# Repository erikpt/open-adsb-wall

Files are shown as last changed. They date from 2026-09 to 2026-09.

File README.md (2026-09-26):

# TailWatch S3 (starter)

MatrixPortal S3 + 128x64 HUB75 panel.

## On the CIRCUITPY drive

- `firmware/boot.py`
- `firmware/code.py`
- `prefs.json` (copy from `firmware/prefs.example.json`)
- `settings.toml` (Wi-Fi only -- copy from `firmware/settings.toml.example`; do **not** set `CIRCUITPY_WEB_API_PASSWORD`)
- `firmware/www/index.html`
- `firmware/lib/prefs.py`, `firmware/lib/sun.py`, `firmware/lib/schedule.py`, `firmware/lib/bbox.py`, `firmware/lib/urldecode.py`, `firmware/lib/tz.py`, `firmware/lib/dim.py`, `firmware/lib/hero.py`
- `firmware/lib/enrich.py`, `firmware/lib/filters.py` (on-device airline lookup + heli/mil/GA filters, issue #2: no cloud)
- `firmware/lib/logos/` (50 generated badge BMPs, ~17.7 KB total -- see `tools/gen_badges.py`)
- `firmware/lib/wifisettings.py` (settings.toml Wi-Fi writer, AP-mode provisioning, issue #11)
- `firmware/lib/setupscreen.py` (panel setup-AP credentials screen, issue #11)
- `firmware/lib/linkwatch.py` (station Wi-Fi drop detection + bounded reconnect watchdog)
- `firmware/lib/httpclient.py` (shared, always-closing adafruit_requests client pattern for the future `firmware/lib/net.py`)

Libraries from the CircuitPython bundle:

- `adafruit_httpserver`
- `adafruit_ntp`
- `adafruit_imageload` (decodes `firmware/lib/logos/*.bmp` badges)
- `adafruit_display_text` (setup-AP credentials screen, `firmware/lib/setupscreen.py`)
- `adafruit_requests`, `adafruit_connection_manager` (needed once `firmware/lib/net.py` starts making HTTPS requests via `firmware/lib/httpclient.py`)

`tests/` (host-side checks, e.g. `tests/test_hero.py`) is plain Python for a
computer's `python3` and is **not** copied to the CIRCUITPY drive.

## Updating files (read-only USB drive)

`firmware/boot.py` remounts CIRCUITPY writable for the firmware so the web UI
can save `/prefs.json` (and `/prefs.bak`). Side effect: in normal operation the
USB drive is **read-only** to your computer.

To update `firmware/code.py`, `firmware/lib/`, or `firmware/www/`:

1. Plug into USB, **hold the UP button**, tap RESET (or power-cycle), and keep
   holding UP about 2 s until the drive mounts.
2. The drive is now writable over USB; copy files. (Web UI prefs saves return
   503 in this mode.)
3. Tap RESET without holding anything to return to normal mode.

Do **not** hold BOOT for this: BOOT at power-up enters the ESP32-S3 ROM
bootloader, not CircuitPython.

Fallbacks: enter safe mode (press RESET, then press RESET again during the ~1 s
yellow status-LED blink); safe mode skips `firmware/boot.py` and leaves the drive
USB-writable. Or from the serial REPL: `import os; os.rename("/boot.py", "/boot.off")`
then hard reset.

`firmware/boot.py` only runs on hard reset/power-up; a soft reload (Ctrl-D,
file save) does not re-run it.

## Behavior

- If an existing board's `settings.toml` has `CIRCUITPY_WEB_API_PASSWORD`, delete
  that line and hard reset. Otherwise Web Workflow holds port 80, the TailWatch
  UI prints "http start failed", and the filesystem is exposed on the LAN.
- Local UI: `http://<s3-ip>/` after it joins Wi-Fi
- Prefs saved on device (`/prefs.json`)
- Sleep blanks the panel (`brightness = 0`)
- Night mode: off / fixed hours / after local sunset
- Day / night / max brightness sliders
- Filters stored: `hide_heli`, `hide_ga`, `hide_mil`
- 10 miles each way → OpenSky bbox (printed to serial until `firmware/lib/net.py` is wired)
- No cloud API -- OpenSky is called directly from the device; hero selection, filters, and airline badges all run on-device (`firmware/lib/hero.py`, `firmware/lib/filters.py`, `firmware/lib/enrich.py`, `firmware/lib/logos/`)
- If Wi-Fi drops, TailWatch retries the join for ~4 min (serial shows `wifi:` lines), moves the web UI to the new IP, and otherwise reboots into the setup AP.

## First-time / new Wi-Fi setup

If `CIRCUITPY_WIFI_SSID` is empty, or the device can't join it, TailWatch
starts its own setup access point:

1. The panel shows four lines: `WIFI SETUP`, the AP name `TailWatch-XXXX`,
   the AP password (`pw xxxxxxxx`), and `192.168.4.1`. The same line is
   printed to serial.
2. On your phone or laptop, join `TailWatch-XXXX` with that password.
3. Open `http://192.168.4.1/`. The Wi-Fi form is shown above the regular
   prefs form, with a note that setup mode is active.
4. Enter your home network's SSID and password (or tick "Open network") and
   tap **Save Wi-Fi & restart**. TailWatch writes `/settings.toml` and hard
   resets to join it.
5. Reconnect your phone to your normal Wi-Fi; find the device's new address
   on serial or in your router's device list.

If the saved credentials are wrong, or that network isn't reachable, the
device comes back up as the `TailWatch-XXXX` setup AP, so there's always an
in-field way to recover. With no SSID configured at all, it stays in setup
mode indefinitely; with an SSID configured but unreachable, it retries the
join automatically after about 10 minutes of no setup-page activity.

Wi-Fi saves need a normal boot (not booted with UP held) since that mode
leaves the filesystem read-only to `firmware/code.py`; a save attempted then
returns 503 and the device does not reboot.

## Next

1. `firmware/lib/net.py`: implement `poll_card()` as an HTTPS GET to OpenSky's `/api/states/all` (bbox + `extended=1`)
2. Draw the returned card with `displayio` / `terminalio` (`firmware/lib/card.py`)
3. Wire `firmware/code.py`'s poll loop: `net.poll_card()` → `filters.apply()` → `hero.select()` → `card.draw()`
4. ~~AP-mode first-boot if `CIRCUITPY_WIFI_SSID` is empty~~ -- done (issue #11)

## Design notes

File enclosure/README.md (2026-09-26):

# TailWatch S3 enclosure (3D-printable, parametric OpenSCAD)

A wall-hung frame for the TailWatch display: an **Adafruit MatrixPortal S3**
plugged straight into the HUB75 input of a **128x64, 2 mm pitch (256 x 128 mm)
indoor panel**. The front stays open. The only thing you see around the LEDs
is the 2.5 mm frame wall, and nothing covers any pixel. USB-C and the
DOWN / UP / RESET buttons are reachable from the edge of the frame while it
hangs on the wall.

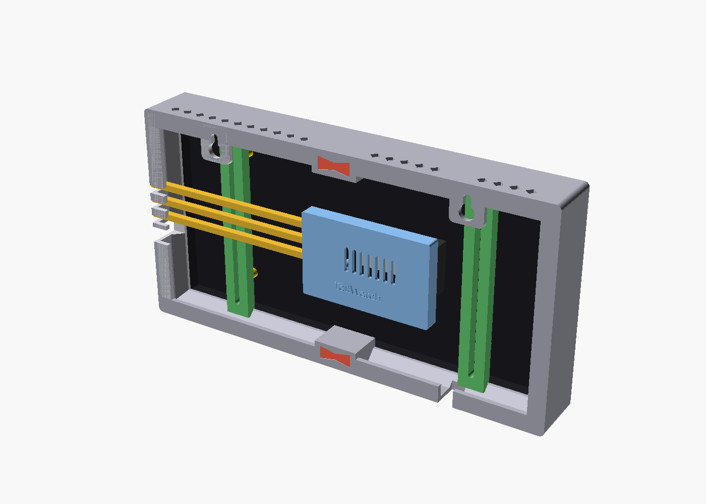
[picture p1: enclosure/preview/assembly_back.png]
back

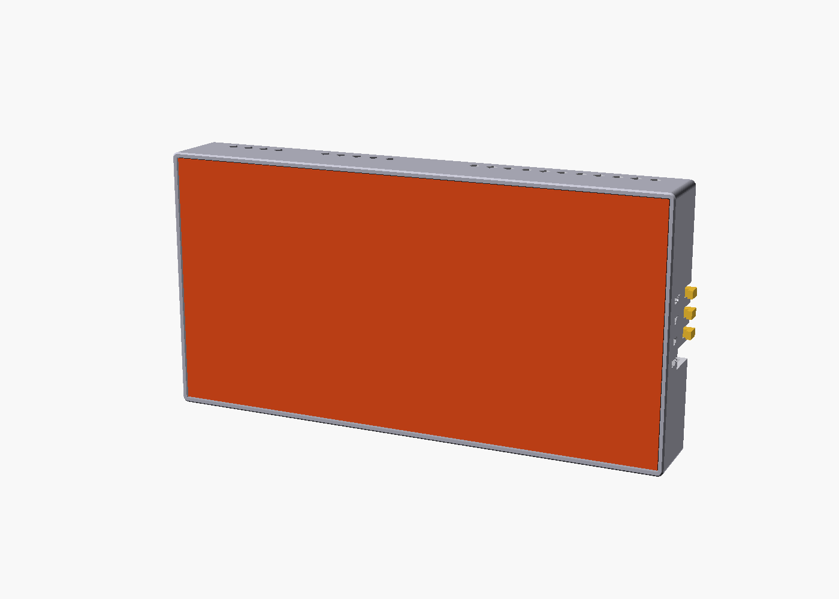
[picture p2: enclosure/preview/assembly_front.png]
front


> **Measure your panel before printing.** The panel is a secondary-market part,
> so its shell depth, mounting-post positions and HUB75 header location vary by
> manufacturer and batch. The model is laid out so that most of that variance
> doesn't change the printed parts, but a few numbers in `params.scad` must
> match your hardware. See [Parameters to check](#parameters-to-check-before-printing).

## Parts

Every part was rendered with OpenSCAD 2021.01 and checked by
`tools/check_stl.py`. The STLs are exported in print orientation, and none
needs supports.

| STL | Qty | What it is | Size as exported (mm) | Print orientation |
|---|---|---|---|---|
| `stl/frame_left.stl`  | 1 | Left half of the perimeter frame, seen from the back (x < `seam_x`). Has the USB and button notches in the default layout. | 131.0 x 134.0 x 35.5 | Wall side down |
| `stl/frame_right.stl` | 1 | Right half of the frame, with the 5 V cable notch. | 131.0 x 134.0 x 35.5 | Wall side down |
| `stl/strap.stl` | 2 (one per `strap_xs` entry) | Slotted rear strap. It screws into the panel's M3 posts, and its bevelled ends lock behind the frame ledges. | 16.0 x 123.0 x 6.9 | Flat side down |
| `stl/portal_pod.stl`  | 1 | Hood over the MatrixPortal S3. It screws to the board's 4 M2.5 holes and carries the push-rod guide tunnels. | 81.5 x 51.4 x 14.2 | Roof down |
| `stl/button_rods.stl` | 1 plate (3 rods) | Push-rods for DOWN, UP and RESET, engraved D / U / R. | 125.5 x 40.7 x 4.0 | Flat, as exported |
| `stl/bowtie_keys.stl` | 1 plate (2 keys) | Bowtie keys that join the frame halves at the top and bottom seams. | 44.0 x 8.0 x 20.8 | Standing, as exported |

**Build volume:** every part must fit the target printer's
**200 x 200 x 250 mm** volume. The largest part (a frame half) is
131 x 134 x 35.5 mm, which leaves more than 60 mm of margin in X and Y. The
panel is 256 mm wide, so the frame is split at `seam_x` into two halves
joined by bowtie keys; no single part needs a big bed. The limit is set in
three places:

- `bed` in `params.scad`, which also drives console warnings for rods or
  frame halves that would outgrow it;
- `BED` in `tools/build.sh`;
- the default in `tools/check_stl.py`.

All three are 200 x 200 x 250, and the checker fails any STL that doesn't fit.

`assembly.scad` is a preview only (dummy panel and board). It is not a part.

### Hardware

- 4x **M2.5 x 6 pan-head** screws: pod to MatrixPortal, driven from under the PCB into the printed posts. Nylon or steel both work. If there is no room under the board, set `pod_fix = "pins"`.
- 2-4x **M3** screws: straps to the panel's threaded posts. The strap is 6.9 mm thick at the slot, so M3 x 10 to M3 x 12 is typical. Check your posts' thread depth and don't bottom out.
- 2x **wall screws**: head 8.5 mm diameter or less, shank 4.3 mm or less (#6/#8 or 3.5-4 mm pan or round head), plus wall anchors. Leave each head standing about 3.5 mm off the wall.
- Optional: a drop of CA glue per bowtie key, and a zip tie on the 5 V cable as a strain-relief stop inside the frame.

## How it works (design notes)

- **Panel retention doesn't depend on the panel's hole pattern.** Each frame
  wall has a 45-degree wedge ledge that sits behind the panel's edge. The two
  straps screw into whatever M3 posts your panel has, and a long slot takes
  any Y position. Each bevelled strap end locks behind the top and bottom
  ledges, so the ledge is clamped between the panel (in front) and the straps
  (behind). You set the strap X positions (`strap_xs`) to match your posts;
  the printed strap is the same either way. If your panel has no posts, the
  strap's front rib can be stuck to the shell with VHB tape instead.
- **Split frame.** The two C-shaped halves slide onto the panel from the left
  and right. Their ledges pass between the panel back and the strap ends, and
  the halves meet at `seam_x`. Bowtie keys dropped in from the back align the
  seam. Structurally the halves are held by the panel edges and the straps,
  so the keys only need to align.
- **Wall mounting: keyhole slots.** There is one keyhole in the top rear
  flange of each half, 160 mm apart. I chose keyholes over a French cleat or
  screw tabs because:
  1. They add no extra parts. A French cleat for a 266 mm frame would be
     another long part to split, and it adds depth.
  2. They're hidden behind the frame.
  3. The whole display (panel about 0.35 kg plus a light frame) lifts off
     the screws without tools when you need the back.

  The slot runs **up** from the entry hole, so the frame drops onto the screw
  heads. With the defaults, drill the two screws **160 mm apart, level, about
  8 mm below where the top edge of the frame will be**.
- **Buttons from the edge.** On the MatrixPortal S3, USB-C, DOWN, UP and
  RESET all sit on one short edge and face sideways, parallel to the panel.
  The panel covers the front and the wall covers the back, so the pod guides
  three printed push-rods from that edge out through notches in the frame
  wall:
  - Each rod has a leg that rests 0.4 mm from its switch plunger.
  - Its finger pad sits outside the wall, and the pad stops against the wall
    after `pad_gap` (2 mm) of travel to protect the switch.
  - Rods ride behind the straps and above the USB plug.
  - Hold the **UP** pad and tap **RST** for USB-writable boot. Hold the
    **DN** pad for 5 s to trigger the easter egg.

  The labels USB / DN / UP / RST are engraved next to the notches. If your
  panel allows it, the nicest layout is `portal_rot = 90`, where the button
  edge faces down, the rods come out of the bottom edge, and they are short.
- **USB-C** stays plugged in: it is the S3's only power, per `../DESIGN.md`.
  The cable leaves through a notch in the same wall. All notches are open
  from the rear, so cables and rods drop in and there is nothing to thread.
- **Panel 5 V** enters through a rear-open notch in the bottom wall
  (`power_notch_x`). The barrel-jack-to-screw-terminal adapter lives inside
  the frame, wired to the panel's power input. Per `../DESIGN.md`, **do not**
  connect the panel supply to the MatrixPortal's M3 power posts, because that
  would back-feed USB.
- **Heat:** the panel draws about 15 W at full white. Diamond vents in the top
  and bottom walls let air rise through the cavity behind the panel. The
  diamond shape needs no bridging.
- **FDM rules followed:** walls are 2 mm or thicker. The ledges are 45-degree
  wedges printed from the wall side. Bridges are 10 mm or less (notch ends,
  rod tunnels). Vents are diamonds, and there are no overhangs past 45
  degrees in the exported orientations.

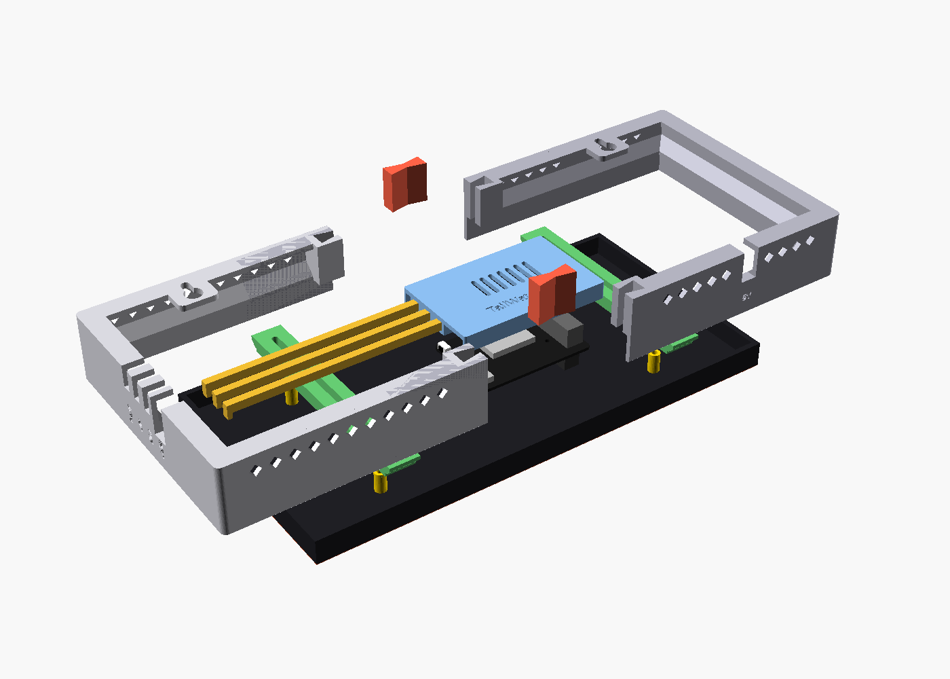
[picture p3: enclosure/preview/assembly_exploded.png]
exploded

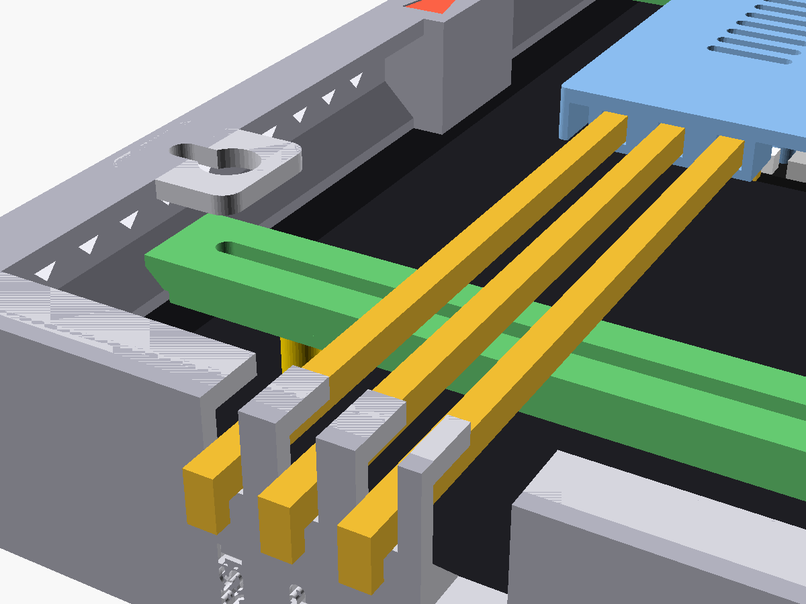
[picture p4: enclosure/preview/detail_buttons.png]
button detail


## Print settings

- **Material: PETG or ASA, not PLA.** The panel runs warm behind the LEDs,
  and the frame sits against its back shell for years. PLA can creep or
  soften at sustained temperatures around 50-60 C; PETG and ASA hold up.
  Printing the push-rods in PETG also keeps them stiff and slippery.
- Layer height: 0.2 mm. Use 0.16 mm for the pod and rods if you want crisper tunnels.
- Walls: 3-4 perimeters (1.2-1.6 mm). Infill: 20-30 % gyroid or grid. Use 100 % for the bowtie keys.
- **Supports: none.** Print every part in the orientation it was exported in.
- A 3-5 mm brim on the frame halves helps against warping, especially with ASA.
- Fit tuning, all in `params.scad` and marked `[TUNE]`:
  - `bt_clr` for the bowtie key fit.
  - `rod_clr` for rod tunnels and notches.
  - `panel_clr` for the panel-to-frame gap.
  - `pod_pilot_d` for the M2.5 self-tap pilot.

## Assembly order

1. **Measure and set the parameters** (next section), then run `tools/build.sh`.
   Check that `assembly.scad` shows no clashes and that the console prints no
   `WARNING` lines.
2. **Pod onto the board.** Set the pod over the MatrixPortal S3, component
   side, with the posts on the 4 mounting holes. Drive 4x M2.5 x 6 from the
   underside of the PCB into the posts. Don't overtighten into plastic.
3. **Straps onto the panel.** Lay the panel face-down on a soft towel. Screw
   the straps to the M3 posts (rib toward the panel, bevelled ends toward the
   top and bottom edges). Leave the screws a half-turn loose.
4. **Slide on the frame halves**, one from each side. Each half's ledge slips
   between the panel back and the strap ends. Push until the halves meet at
   the seam, then drop the two bowtie keys into the seam bosses from the
   back. Add glue if you like. Tighten the strap screws.
5. **Wire the 5 V feed.** Mount the barrel-jack adapter to the panel's power
   leads and lay the supply cable into the bottom notch. A zip tie around the
   cable inside the frame makes a pull stop.
6. **Rods into the pod.** Feed each rod's straight end out through its
   tunnel, from the board side, so the leg stays on the board side. D / U / R
   are engraved next to the pads.
7. **Plug in the MatrixPortal.** Press the board, pod and rods straight onto
   the panel's HUB75 input header by pushing on the pod roof. The rods drop
   into their wall notches with the pads outside.
8. **USB-C cable** into the port, laid into the USB notch. The cable can bow
   over a strap if one is in the way.
9. **Hang it:** put the keyholes over the two wall screws and let it drop.

## Parameters to check before printing

All values live in `params.scad`, grouped and commented. Coordinates are in
the **back view**: stand behind the panel, with X to your right, Y up, and
(0,0) at the panel's lower-left corner as seen from the back. Z is measured
from the LED face toward the wall. With the defaults, the button side is on
the display's **right** when you face it, because the back view is mirrored.

| Parameter | Default | Status | How to measure |
|---|---|---|---|
| `panel_thk` | 13.0 | **MEASURE** | LED face to the rearmost flat of the plastic shell, ignoring connectors. 13 mm is a typical listing value for P2 256x128 modules. |
| `hub75_in_xy` | [176, 64] | **PLACEHOLDER** | Centre of the HUB75 **input** header, back view. |
| `portal_rot` | 0 | **MEASURE** | Which way the board's USB/button edge points once plugged in: 0 = left, 90 = down, 180 = right, 270 = up (back view). |
| `portal_pcb_z` | 15.5 | **MEASURE** | Most important depth. With the board plugged in and the panel face-down on a table, this is the height of the MatrixPortal **PCB underside** above the table. For `pod_fix = "screws"` it must be at least `panel_thk + 2.2` so the M2.5 heads fit under the board; otherwise use `"pins"`. |
| `strap_xs` | [48, 208] | **PLACEHOLDER** | X of a column of M3 posts on each half. The strap must not cross the pod; the console warns if it does. |
| `panel_holes` | 4 corner-ish posts | **PLACEHOLDER** | Only used by the preview and the "strap lines up with a post" check. |
| `power_notch_x` | 200 | **PLACEHOLDER** | Put it near your panel's power input. |
| `keyhole_spacing` | 160 | choice | Distance between the two wall screws. |
| `pod_fix` | "screws" | choice | "screws" (4x M2.5) or "pins" (printed press-fit pins, no under-board room needed). |
| `pad_gap` | 2.0 | TUNE | Button over-travel stop. Reduce it only after test-fitting. |

Changing any of these moves the notches, rod lengths, pod position and frame
depth together. `frame_back_z` is automatic: it sits just behind the pod plus
`wall_gap_min`. The console echoes the result (34.5 mm for the defaults).

## What was verified vs. what is assumed

**Verified from Adafruit's published design files.** The Learn Guide and
product pages were unreachable from the build environment, so these come from
Adafruit's GitHub instead:

- MatrixPortal S3 PCB outline: **63.5 x 44.45 mm** (2.50" x 1.75"), corner radius 2.54 mm, 1.6 mm thick. Source: board outline (layer 20) in `Adafruit MatrixPortal S3.brd`. Adafruit's listing gives 63.6 x 44.3 x 20.0 mm overall.
- Mounting holes: 4x **2.5 mm** plated, at (7.62, 15.875), (7.62, 35.56), (48.26, 15.875) and (48.26, 35.56) mm from the lower-left corner in the Eagle top view.
- **USB-C** (CUI CUSB31-CFM2AX, top mount): mouth flush with the x = 0 short edge, centred at y = 8.255 mm.
- **Buttons** (E-Switch TL3330 right-angle), on the same edge with plungers pointing outward:
  - DOWN at y = 18.542 mm.
  - UP at y = 28.321 mm.
  - RESET at y = 38.100 mm.
  - Plunger tips at x = -1.07 / -0.94 / -0.44 mm, centre 3.37 mm above the PCB underside. The plunger positions come from Adafruit's 3D model.
- **HUB75:**
  - A **2x10 female socket on the underside** plugs onto the panel's 2x8 header. Adafruit's README says it "fits snugly into 2x8 HUB75 ports".
  - The socket is 5.33 x 25.4 mm and 5.55 mm deep below the PCB (3D model).
  - A **2x8 shrouded IDC plug on the top** is the output. Both are centred at (57.15, 22.225) mm, along the far short edge.
  - The IDC shroud is the tallest top-side part, at 10.64 mm above the PCB.
- **Power posts:** M3 SMT nuts at (58.42, 4.445) and (58.42, 40.132) mm.
- Closest top-side part to a mounting hole: the 100 uF cap, 2.65 mm from hole 1. The pod posts are therefore 4.6 mm in diameter.

**Not verified. These are adjustable, with generous clearances:**

- **Panel mounting-post positions and diameter.** No mechanical drawing is
  published for these panels. Adafruit said on its forum that it buys them on
  the secondary market and has no control over mounting-hole placement. The
  slotted-strap design means the printed parts don't depend on them.
- **Panel shell thickness** (13 mm from listings), **HUB75 header location**,
  box-header height, and so **`portal_pcb_z`**. All must be measured.
- **Location of the panel's power input.**
- **Switch plunger travel** (TL3330 datasheet not checked). The rod rest gap
  is 0.4 mm with a 2 mm hard stop, and both are tunable.
- **USB-C plug overmold size.** The notch (10 mm) is sized for the cable; the
  plug itself stays inside the frame.

## Rebuilding and checking

```sh
enclosure/tools/build.sh
```

This exports every STL, renders `preview/*.png` (it uses `xvfb-run` when
there is no display), and runs `tools/check_stl.py`. The checker reports, per
file:

- facet count;
- bounding box against the 200 x 200 x 250 mm bed;
- enclosed volume;
- an edge-manifold test: every edge must be shared by exactly two triangles, in opposite directions.

OpenSCAD's own logs are written to `logs/` and report `Simple: yes` and the
volume and facet counts for each part.

Last run: all 6 STLs are manifold and fit the **200 x 200 x 250 mm** bed.
The largest is 131.0 x 134.0 x 35.5 mm (frame halves); the longest is the
rod plate at 125.5 mm. For robustness I also
rendered `portal_rot` = 90, 180 and 270 with other header positions, and
`pod_fix = "pins"`. All of them came out manifold and in-bed.

## Blender file (.blend) and web 3D viewer (.glb)

`tailwatch_enclosure.blend` is a native Blender scene showing all 6 printed
parts in their **assembled** position (plus the panel and MatrixPortal
reference/"dummy" geometry, for context), each as its own named, colored
object: `frame_left`, `frame_right`, `strap_1`, `strap_2`, `portal_pod`,
`button_rods`, `bowtie_key_1`, `bowtie_key_2`, `panel_dummy`, `portal_dummy`.
Colors match the `assembly()` preview's `color()` calls (frame halves grey,
pod blue, rods yellow, straps green, bowtie keys tomato red).

It is **not** re-derived from scratch in `bpy` -- that would risk a subtle
mismatch with the OpenSCAD source of truth. Instead:

1. `blender_import/*_positioned.scad` -- one small wrapper per part (plus
   `panel_dummy`/`portal_dummy`) that applies the *exact* transform
   `assembly()` uses in `tailwatch_lib.scad` (`on_board()`, `frame_half(0/1)`,
   the `strap_xs` loop, the bowtie `seam_x` placement, ...) around just that
   part's raw module, at `explode = 0`.
2. `tools/export_blender_stls.sh` runs OpenSCAD on each wrapper, producing
   `blender_import/*.stl` in true assembly position (distinct from the
   print-orientation STLs in `stl/`).
3. `tools/blender_build.py` (run headless: `blender --background --python
   tools/blender_build.py`) imports each STL as its own object, assigns its
   material/color, lights and renders 3 views to
   `preview/blender_front.png`, `preview/blender_iso.png`,
   `preview/blender_back.png` (1600x1200, Eevee), saves
   `tailwatch_enclosure.blend`, and exports a combined
   `web/tailwatch_enclosure.glb` (glTF binary, ~0.24 MB) for embedding with
   Google's `<model-viewer>` web component.

To regenerate after an OpenSCAD change:

```sh
enclosure/tools/export_blender_stls.sh
blender --background --python enclosure/tools/blender_build.py
```

(Blender's bundled Python needs `numpy` for its glTF exporter addon; if you
see `ModuleNotFoundError: No module named 'numpy'` the first time, find
Blender's Python with `blender --background --python-expr "import sys;
print(sys.executable)"` and `pip install --break-system-packages numpy`
into it.)

## STEP file (parametric CadQuery rebuild)

`step/` contains a **from-scratch CadQuery (OCCT/BREP) reconstruction** of
the 6 printable parts, exported as real STEP solids (`step/*.step`) plus
matching STLs (`step/*_cq.stl`) for verification. This is the one
deliverable that couldn't be produced by transforming the existing OpenSCAD
export: STL is a mesh, and STEP needs an actual boundary-representation
solid, so the geometry is rebuilt in CadQuery from the same numbers in
`params.scad`.

- `step/tailwatch_params.py` -- a manual, literal transcription of
  `params.scad`'s values and its `DERIVED VALUES` section into Python
  (kept in the same order, so a diff against `params.scad` is easy).
- `step/cadquery_build.py` -- builds all 6 parts and exports them, in the
  same **print orientation** as `stl/*.stl` (via the same
  `frame_print()`/`strap_print()`/`pod_print()`/`rods_print()`/
  `keys_print()` transforms), so bounding boxes can be compared directly.
  Regenerate with `python3 step/cadquery_build.py` (needs `pip install
  cadquery`).

**Simplifications vs. the OpenSCAD design** (documented in detail in that
file's docstring; all are subtractive/cosmetic and do not change any
part's overall envelope): no corner fillets/front chamfer on the frame, no
diamond vents, no power/USB/button-rod side notches, no engraved text, the
MatrixPortal pod is a solid roof+skirt block (no hollow skirt or roof
vents), and the strap omits the 45-degree wedge-envelope corner relief.
**Kept faithfully**: the frame's wedge retention ledges, rear flange, both
keyhole slots and the seam boss + bowtie-key pocket; the bowtie keys'
hexagonal profile; the strap's slab + rib + M3 slot; the pod's 4 M2.5
mounting posts (at their exact hole coordinates) with pilot holes and the
push-rod guide block with its 3 rod tunnels; the rods' exact profile.

**Dimensional cross-check** (`tools/check_stl.py stl/*.stl step/*_cq.stl`,
bounding box in mm, OpenSCAD vs. CadQuery):

| Part | OpenSCAD (stl/) | CadQuery (step/) | Diff |
|---|---|---|---|
| bowtie_keys | 44.0 x 8.0 x 20.8 | 44.0 x 8.0 x 20.8 | 0 |
| button_rods | 125.5 x 40.7 x 4.0 | 125.5 x 40.7 x 4.0 | 0 |
| frame_left | 131.0 x 134.0 x 35.5 | 131.0 x 134.0 x 35.5 | 0 |
| frame_right | 131.0 x 134.0 x 35.5 | 131.0 x 134.0 x 35.5 | 0 |
| portal_pod | 81.5 x 51.4 x 14.2 | 81.5 x 51.5 x 14.2 | 0.1 mm (Y) |
| strap | 16.0 x 123.0 x 6.9 | 16.0 x 123.0 x 6.9 | 0 |

All 6 parts pass, well within a "few mm" tolerance -- 5 of 6 are an exact
bounding-box match and the pod is off by 0.1 mm. Volumes differ more (e.g.
the pod: 14.2 cm3 hollow original vs. 38.0 cm3 solid-block CadQuery
simplification) exactly where the simplifications above remove hollow/vented
material, as expected. Every exported STEP file was re-imported with
CadQuery and confirmed to be a single valid solid (2 for the bowtie-key
pair, 3 for the rods) with a matching bounding box.

## Files

| File | Purpose |
|---|---|
| `params.scad` | **All adjustable parameters**, derived values and sanity checks. |
| `tailwatch_lib.scad` | Geometry for every part, in assembled position, plus the print orientations. |
| `frame_left.scad`, `frame_right.scad`, `strap.scad`, `portal_pod.scad`, `button_rods.scad`, `bowtie_keys.scad` | One file per printable part. |
| `assembly.scad` | Preview. Use `-D explode=40` for exploded and `-D upright=true` for the wall-hung orientation. |
| `tools/build.sh`, `tools/check_stl.py` | Build and verification scripts. |
| `stl/`, `preview/`, `logs/` | Generated output. |
| `blender_import/` | Positioned-STL wrappers/exports used to build the Blender file. |
| `tailwatch_enclosure.blend` | Native Blender scene, assembled position, per-part materials. |
| `web/tailwatch_enclosure.glb` | Combined glTF binary for `<model-viewer>` embedding. |
| `tools/export_blender_stls.sh`, `tools/blender_build.py` | Regenerate the positioned STLs / the .blend + previews + .glb. |
| `step/` | CadQuery rebuild: `tailwatch_params.py`, `cadquery_build.py`, `*.step`, `*_cq.stl`. |

## Sources

- Adafruit MatrixPortal S3 PCB (Eagle `.brd`/`.sch`): <https://github.com/adafruit/Adafruit-MatrixPortal-S3-PCB>
- Adafruit CAD parts, "5778 Matrix Portal S3" STEP/STL: <https://github.com/adafruit/Adafruit_CAD_Parts>
- Product page (dimensions quoted via search listing): <https://www.adafruit.com/product/5778>. Learn Guide pinouts: <https://learn.adafruit.com/adafruit-matrixportal-s3/pinouts>
- Adafruit forum, "Mechanical drawing of 64x64 P2 matrix" (no drawings, hole placement not controlled): <https://forums.adafruit.com/viewtopic.php?t=220587>
- Typical P2 256x128 module listing (13 mm thickness, 128x64, HUB75E): <https://www.amazon.com/Indoor-128x64-Module-256mm128mm-256128mm/dp/B0869P1DCH>
- Project hardware and power notes: `../DESIGN.md` section 3 (panel on external 5 V, S3 on USB-C only).

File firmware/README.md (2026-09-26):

# TailWatch S3 (starter)

MatrixPortal S3 + 128x64 HUB75 panel.

## On the CIRCUITPY drive

- `boot.py`
- `code.py`
- `prefs.json` (copy from `prefs.example.json`)
- `settings.toml` (Wi-Fi only -- copy from `settings.toml.example`; do **not** set `CIRCUITPY_WEB_API_PASSWORD`)
- `www/index.html`
- `lib/prefs.py`, `lib/sun.py`, `lib/schedule.py`, `lib/bbox.py`, `lib/urldecode.py`, `lib/tz.py`, `lib/dim.py`, `lib/hero.py`
- `lib/enrich.py`, `lib/filters.py` (on-device airline lookup + heli/mil/GA filters, issue #2: no cloud)
- `lib/logos/` (50 generated badge BMPs, ~17.7 KB total -- see `tools/gen_badges.py`)
- `lib/wifisettings.py` (settings.toml Wi-Fi writer, AP-mode provisioning, issue #11)
- `lib/setupscreen.py` (panel setup-AP credentials screen, issue #11)
- `lib/linkwatch.py` (station Wi-Fi drop detection + bounded reconnect watchdog)
- `lib/httpclient.py` (shared, always-closing adafruit_requests client pattern for the future `lib/net.py`)

Libraries from the CircuitPython bundle:

- `adafruit_httpserver`
- `adafruit_ntp`
- `adafruit_imageload` (decodes `lib/logos/*.bmp` badges)
- `adafruit_display_text` (setup-AP credentials screen, `lib/setupscreen.py`)
- `adafruit_requests`, `adafruit_connection_manager` (needed once `lib/net.py` starts making HTTPS requests via `lib/httpclient.py`)

`tests/` (host-side checks, e.g. `tests/test_hero.py`) is plain Python for a
computer's `python3` and is **not** copied to the CIRCUITPY drive.

## Updating files (read-only USB drive)

`boot.py` remounts CIRCUITPY writable for the firmware so the web UI can save
`/prefs.json` (and `/prefs.bak`). Side effect: in normal operation the USB drive
is **read-only** to your computer.

To update `code.py`, `lib/`, or `www/`:

1. Plug into USB, **hold the UP button**, tap RESET (or power-cycle), and keep
   holding UP about 2 s until the drive mounts.
2. The drive is now writable over USB; copy files. (Web UI prefs saves return
   503 in this mode.)
3. Tap RESET without holding anything to return to normal mode.

Do **not** hold BOOT for this: BOOT at power-up enters the ESP32-S3 ROM
bootloader, not CircuitPython.

Fallbacks: enter safe mode (press RESET, then press RESET again during the ~1 s
yellow status-LED blink); safe mode skips `boot.py` and leaves the drive
USB-writable. Or from the serial REPL: `import os; os.rename("/boot.py", "/boot.off")`
then hard reset.

`boot.py` only runs on hard reset/power-up; a soft reload (Ctrl-D, file save)
does not re-run it.

## Behavior

- If an existing board's `settings.toml` has `CIRCUITPY_WEB_API_PASSWORD`, delete
  that line and hard reset. Otherwise Web Workflow holds port 80, the TailWatch
  UI prints "http start failed", and the filesystem is exposed on the LAN.
- Local UI: `http://<s3-ip>/` after it joins Wi-Fi
- Prefs saved on device (`/prefs.json`)
- Sleep blanks the panel (`brightness = 0`)
- Night mode: off / fixed hours / after local sunset
- Day / night / max brightness sliders
- Filters stored: `hide_heli`, `hide_ga`, `hide_mil`
- 10 miles each way → OpenSky bbox (printed to serial until `lib/net.py` is wired)
- No cloud API -- OpenSky is called directly from the device; hero selection, filters, and airline badges all run on-device (`lib/hero.py`, `lib/filters.py`, `lib/enrich.py`, `lib/logos/`)
- If Wi-Fi drops, TailWatch retries the join for ~4 min (serial shows `wifi:` lines), moves the web UI to the new IP, and otherwise reboots into the setup AP.

## First-time / new Wi-Fi setup

If `CIRCUITPY_WIFI_SSID` is empty, or the device can't join it, TailWatch
starts its own setup access point:

1. The panel shows four lines: `WIFI SETUP`, the AP name `TailWatch-XXXX`,
   the AP password (`pw xxxxxxxx`), and `192.168.4.1`. The same line is
   printed to serial.
2. On your phone or laptop, join `TailWatch-XXXX` with that password.
3. Open `http://192.168.4.1/`. The Wi-Fi form is shown above the regular
   prefs form, with a note that setup mode is active.
4. Enter your home network's SSID and password (or tick "Open network") and
   tap **Save Wi-Fi & restart**. TailWatch writes `/settings.toml` and hard
   resets to join it.
5. Reconnect your phone to your normal Wi-Fi; find the device's new address
   on serial or in your router's device list.

If the saved credentials are wrong, or that network isn't reachable, the
device comes back up as the `TailWatch-XXXX` setup AP, so there's always an
in-field way to recover. With no SSID configured at all, it stays in setup
mode indefinitely; with an SSID configured but unreachable, it retries the
join automatically after about 10 minutes of no setup-page activity.

Wi-Fi saves need a normal boot (not booted with UP held) since that mode
leaves the filesystem read-only to `code.py`; a save attempted then returns
503 and the device does not reboot.

## Next

1. `lib/net.py`: implement `poll_card()` as an HTTPS GET to OpenSky's `/api/states/all` (bbox + `extended=1`)
2. Draw the returned card with `displayio` / `terminalio` (`lib/card.py`)
3. Wire `code.py`'s poll loop: `net.poll_card()` → `filters.apply()` → `hero.select()` → `card.draw()`
4. ~~AP-mode first-boot if `CIRCUITPY_WIFI_SSID` is empty~~ -- done (issue #11)

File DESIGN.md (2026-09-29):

# TailWatch — Design Document for Coding Agents

Status: implementable MVP  
Hardware target: Adafruit MatrixPortal S3 + indoor P2 SMD1515 128×64 HUB75 panel  
Companion: none -- the device calls OpenSky directly and assembles cards on-device (see issue #2; no cloud API)  
Existing starter: `firmware/` (`code.py`, `lib/*`, `www/index.html`, `prefs.example.json`)

This document is the spec. Do not invent product scope beyond it. Prefer small, working slices over frameworks.

---

## 1. Goal

A wall display that shows **one live aircraft card** for traffic near a user-configured GPS point, without requiring a subscription app.

Two physical units will exist (owner + friend). Each unit owns its own lat/lon and display prefs on-device, and assembles its own flight cards and badges locally (issue #2: no cloud tier). OpenSky (or compatible ADS-B) is the position source.

## 2. Non-goals (MVP)

- Multi-aircraft list or map on the LED panel
- On-device SQLite of the global fleet
- Captive-portal polish matching consumer routers
- Official airline trademark licensing (use simple letter marks / public-domain style sprites)
- Bonjour across the internet
- Driving more than one 128×64 panel
- Pi Pico / Pi Zero in v1 (allowed later; do not block S3-only path)

## 3. Hardware and power

| Piece | Spec |
|---|---|
| Controller | Adafruit MatrixPortal S3 (ESP32-S3, USB-C, HUB75, Wi-Fi) |
| Panel | P2-1515, 128×64, 256×128 mm, 1/32 scan, HUB75 |
| Panel power | External 5.0 V bench/PSU, **direct to the panel's own power input**, ~3 A measured full white (~15 W), budget 4–5 A |
| S3 power | USB-C only (board + logic) — its screw terminals are output-only, never a power input (see footgun below). Can share the panel's PSU via a second USB-C feed; do not wire the panel 5 V onto the S3's screw terminals |
| Wiring | HUB75 data from S3; panel 5 V/GND from PSU **wired to the panel itself**; common ground optional if noise appears |
| S3 power cable | Bare-wire-to-USB-C pigtail (5V, 3–5 A), spliced onto the same PSU as the panel rather than a second USB-C brick (see footgun note below) |

Firmware must never assume USB can power the LEDs.

**Known footgun (confirmed on hardware):** the MatrixPortal S3 has its own 5V/GND screw
terminals next to the HUB75 connector -- these are **output only**, wired straight to the
board's USB-C 5V rail, and exist so the board can drive a *small* panel with no external
supply at all. Landing the external PSU's barrel-to-terminal adapter on *those* terminals
instead of the *panel's own* power input looks correct but isn't: the panel ends up
entirely dependent on USB, and unplugging USB-C kills it even though a beefy external
supply is nominally connected. There is no actual backfeed in this case -- the panel
simply never had independent power. Always verify the PSU leads land on the panel's own
power pads/terminal, never the MatrixPortal's screw lugs.

**Powering both from one supply.** The S3's screw terminals being output-only doesn't
mean the board must run off a separate USB-C wall charger -- it means the board has to
be fed through its USB-C port specifically, same as always, just sourced from the same
PSU as the panel instead of a second brick. Land the PSU's 5V/GND leads on a small
junction (splice or terminal block) with two branches out of it: one straight to the
panel's own power input (as above, carries the bulk of the current), and one through a
**bare-wire-to-USB-C pigtail cable** into the MatrixPortal's USB-C port. That pigtail is
passive -- two wires to VBUS/GND, no PD negotiation -- so it presents the same fixed 5V
the board would see from any USB-C charger. Size the PSU for the panel's worst-case draw
plus the board's (well under 1A even with Wi-Fi active); the panel dominates the budget
either way. See the table above for a specific cable.

## 4. Architecture

```
[Phone browser]
    |  http://<s3-ip>/  or 192.168.4.1  (prefs only)
[MatrixPortal S3]
    |  firmware/lib/net.py: GET /api/states/all?lamin&lomin&lamax&lomax&extended=1
    |  (OpenSky token optional, only to raise the anonymous rate limit)
[OpenSky / ADS-B]
    + on-device firmware/lib/hero.py, firmware/lib/filters.py, firmware/lib/enrich.py, firmware/lib/logos/
```

No cloud tier (issue #2): each device polls OpenSky directly with its own
bbox and assembles/filters/enriches the card locally.

**On device (everything; no cloud copy of anything):** GPS, radius, brightness, sleep, night mode, filters, OpenSky token (optional), positions (fetched live, never persisted), enrichment tables, badges.

## 5. Device identity (two units)

- Each unit's `/prefs.json` (lat/lon, filters, OpenSky token) is entirely local -- nothing is shared or centrally stored, so there's no cross-device isolation to get wrong
- Same firmware image on both units
- Optional `device_id` printed on serial at boot for support

Provisioning MVP: owner pastes token + API URL in the local settings page. No account system required for two devices.

## 6. Preferences (on-device)

File: `/prefs.json` with `/prefs.bak` on write.

```json
{
  "lat": 30.0000,
  "lon": -95.0000,
  "nm": 10,
  "hide_heli": true,
  "hide_ga": false,
  "hide_mil": true,
  "brightness_day": 0.70,
  "brightness_night": 0.18,
  "brightness_max": 1.00,
  "night_mode": "sunset",
  "night_start": "21:00",
  "night_end": "06:30",
  "sleep_enabled": true,
  "sleep_start": "23:00",
  "sleep_end": "06:30",
  "tz_offset_min": -360,
  "us_dst": true,
  "api": "https://opensky-network.org/api",
  "token": ""
}
```

Rules:

- `nm` is miles **in each direction** (square bbox), clamp 1–50
- brightness fields 0.0–1.0; day/night clamped to `brightness_max`
- `night_mode`: `off` | `fixed` | `sunset`
- sleep and night mode are independent: sleep blanks the panel; night only dims
- booleans from HTML checkboxes: missing key on POST means `false`
- JSON POSTs are partial merges: omitted keys (including booleans) keep their stored value; JSON booleans are used as-is
- `tz_offset_min` + `us_dst` used for sleep/fixed night windows (firmware/lib/tz.py, fixed US DST rule only); sunset uses lat/lon solar math (UTC timestamps)

Apply prefs immediately on save except Wi-Fi credentials (Wi-Fi stays in `settings.toml` for MVP).

### Bounding box

```
dlat = nm / 69.0
dlon = nm / (69.0 * cos(lat_rad))
lamin, lamax = lat ± dlat
lomin, lomax = lon ± dlon
```

Existing helper: `firmware/lib/bbox.py`.

### Schedule

Existing helpers: `firmware/lib/sun.py`, `firmware/lib/schedule.py`.

Every ~1 s (or on prefs save):

1. If sleep window → `display.brightness = 0`, skip network poll
2. Else if night → `min(brightness_night, brightness_max)`
3. Else → `min(brightness_day, brightness_max)`

Dimming is done by scaling draw colours (`firmware/lib/dim.py` Dimmer). `display.brightness` is on/off on rgbmatrix, so it stays 1.0 while awake and 0.0 only for the black sleep state (blank group).

NTP at boot (UTC into RTC). The RTC and `sun.py` stay UTC. `schedule.py` computes local time as UTC + `tz_offset_min` (+60 min under the fixed US DST rule when `us_dst`) via `firmware/lib/tz.py`. No tz database: only the fixed US rule is supported.

**Clock-trust gate (issue #11).** NTP can fail (no internet yet, AP mode, a
flaky router), and after `microcontroller.reset()` the RTC may hold either a
real time it kept across the reset, or CircuitPython's built-in epoch
(commonly 2000-01-01). `firmware/lib/schedule.py:clock_trusted(ts=None)` returns true
if NTP has synced this boot (`set_clock_synced(True)`, called by `firmware/code.py`'s
`sync_clock()`), or if `ts` (default `time.time()`) is already
`>= MIN_TRUSTED_TS` (2024-01-01T00:00Z) -- the RTC-survived-reset case.
`sleeping()` and `night()` return `False` when the clock isn't trusted
(never blank the panel or apply night dimming on a bogus timestamp);
`brightness()` then falls through to `min(brightness_day, brightness_max)`.
`GET /api/status` exposes both `clock_synced` and `clock_trusted` so the web
UI can show a "clock not set" banner.

## 7. Local web UI

Static files in `/www`. Server: `adafruit_httpserver` on port 80. Web Workflow
(CIRCUITPY_WEB_API_PASSWORD) must stay disabled -- it also binds port 80 and
exposes the filesystem.

| Route | Method | Purpose |
|---|---|---|
| `/` | GET | `firmware/www/index.html` |
| `/api/prefs` | GET | current JSON minus `token`, plus `token_set` (`firmware/lib/prefs.py:public()`) |
| `/api/prefs` | POST | form or JSON merge → save → apply brightness (station mode only) |
| `/api/status` | GET | `{mode, ip, ssid, ap_ssid, networks, clock_synced, clock_trusted, rebooting, wifi_drops}` -- never a password |
| `/api/wifi` | POST | JSON or form `{ssid, password, open}` → `firmware/lib/wifisettings.py` → `/settings.toml` → hard reset (§ AP mode below) |

All `/api/*` routes require `Host` to be the device's own current address;
POSTs also require a same-origin `Origin`/`Referer`, else `403` (`firmware/lib/reqguard.py`,
issue #14). Reaching the UI by a DNS name instead of its IP therefore returns
403 on every `/api/*` call -- the UI is documented as `http://<ip>/`, not a
hostname.

UI fields must match the schema in §6 (already drafted in `firmware/www/index.html`).

MVP discovery: print IPv4 on serial and on the LED (`SETUP 192.168.x.x`) if no card yet. mDNS `tailwatch.local` is a stretch goal (CircuitPython support is uneven).

### AP mode (first boot, issue #11)

If `CIRCUITPY_WIFI_SSID` is empty, or joining it fails (two 10 s
`wifi.radio.connect()` attempts, ~20 s total):

- Scan for nearby networks first (`wifi.radio.start_scanning_networks()`,
  before `stop_station()` -- the radio can't scan once it's AP-only), for the
  UI's SSID datalist and to pick whichever of channels 1/6/11 has the fewest
  networks.
- Start a **WPA2, password-protected** AP `TailWatch-XXXX` (last two MAC
  bytes), `wifi.radio.start_ap(ssid, pw, channel=…, authmode=[WPA2, PSK],
  max_connections=2)`. The password is 8 random characters from a 32-symbol
  alphabet (no `l`/`o`/`0`/`1`), generated fresh every boot with
  `os.urandom`, never persisted, and only shown on the panel (and serial) --
  not open, because `POST /api/wifi` can repoint the device at another
  network, so being able to read the password proves you're standing at
  the device.
- Serve the same UI at `wifi.radio.ipv4_address_ap` (normally
  `192.168.4.1`); the Wi-Fi form is shown above the regular prefs form.
- Prefs save still writes `/prefs.json`, but the dimmer/brightness path is
  skipped in AP mode (`display.brightness = 1.0`, fixed `0x707070` setup
  text via `firmware/lib/setupscreen.py`, so a slider at 0 or a sleep window can't
  hide the password).
- No NTP attempt in AP mode (there is no internet).
- `POST /api/wifi` is the **only** allow-listed `settings.toml` writer
  (`firmware/lib/wifisettings.py`): it reads just `ssid`, `password`, `open` from the
  body (JSON or form; the body parser never reads the query string for this
  route, so a password can't leak into a URL/log), validates them, and
  rewrites just the two `CIRCUITPY_WIFI_*` keys via a `.new` →
  `path`↔`.bak` → rename swap (crash-safe; `recover()` finishes an
  interrupted swap on the next boot). Everything else in `settings.toml` is
  kept, and the previous file survives as `settings.toml.bak`. Wi-Fi is
  deliberately **not** part of the `/prefs.json` schema (§6).
  - On success: `{ok, ssid, rebooting: true}`, then
    `microcontroller.reset()` about 3 s later (after the reply flushes).
    The hard reset re-runs `firmware/boot.py` (remounts read-write) and the
    CircuitPython supervisor, which re-reads `settings.toml` and auto-joins;
    if the new credentials are wrong the device comes back up as the setup
    AP, so there's always an in-field recovery path.
  - `ValueError` (bad SSID/password) → 400 with the message; `OSError`
    (booted with UP held, filesystem read-only) → 503, same pattern as
    `/api/prefs`, and the device does not reboot.
- **Idle retry.** If an SSID *is* configured (e.g. the router was
  rebooting), the device reboots to retry the join after 600 s with no
  `/api/*` request. The setup page polls `/api/status` every 60 s while in
  AP mode, which keeps the device up while someone has it open. With no
  SSID configured at all, the device stays in AP mode indefinitely.

Hold BOOT 5 s to clear Wi-Fi settings is a stretch goal.

**Captive-portal auto-pop (issue #21).** A plain setup AP with no DNS/HTTP
tricks leaves a joining phone/laptop's own network stack unable to tell
there's anything to sign in to -- its captive-portal detection probes just
time out (AP mode has no internet to resolve or reach anything real), so the
OS never auto-launches a sign-in browser and the user has to already know to
browse to `192.168.4.1`. Two pieces make that auto-pop instead, both AP-mode
only:

- **DNS hijack** (`firmware/lib/captiveportal.py`, `CaptiveDNS`): a UDP responder
  bound to `:53` on the AP-mode `socketpool.SocketPool`, polled once per main
  loop tick (`captive_dns.poll()`, non-blocking). It answers every class-IN
  A or ANY query with the AP's own IPv4 address, and every other query type
  (AAAA, HTTPS/SVCB, ...) with a NOERROR/no-answer reply so the resolver
  falls through to an A query instead of stalling. It is not a general
  resolver -- there's nothing upstream to forward anything to -- and drops
  anything malformed or multi-question rather than guess at it. This is what
  makes the OS's captive-portal probe hostnames (e.g. Apple's
  `captive.apple.com`) resolve to this device at all.
- **HTTP redirects for the known OS probe paths** (`firmware/code.py`,
  `CAPTIVE_CHECK_PATHS` / `captive_redirect`): Android (`/generate_204`,
  `/gen_204`), Apple (`/hotspot-detect.html`,
  `/library/test/success.html`), Windows (`/connecttest.txt`, `/ncsi.txt`,
  `/redirect`), and Firefox (`/success.txt`), registered only
  `if ap_mode`. Each OS actually expects one specific "you have real
  internet" response (Android: bare 204; Apple: one exact HTML string;
  Windows: specific plain-text bodies) and treats *anything else* as "there's
  a portal here" -- so a redirect to `http://<host>/` is enough to trigger
  that path; trying to instead mimic each OS's exact expected success body
  would be more code for the same result and would have to be kept in sync
  with OS behavior that can change.

Together: DNS hijack gets the probe request to this device; the redirect
response is what makes the OS conclude a portal is present and open its
sign-in browser to it.

### Wi-Fi drop recovery (station mode)

Once joined as a station, `firmware/lib/linkwatch.py:LinkWatch` (`firmware/code.py`, station mode
only; `link = None` in AP mode) watches for a dropped link and re-joins it,
because CircuitPython's own retries are limited and `adafruit_httpserver`
otherwise keeps a listening socket bound to the address that just went away:

- Checks `wifi.radio` every 2 s. A drop waits 10 s (grace period, so
  CircuitPython's own few retries can run first), then makes up to 6
  reconnect attempts with gaps 10 / 20 / 30 / 60 / 60 / 60 s between them (about
  4 minutes total from the drop).
- Recovered (its own `connect()`, or the radio recovering on its own) or the
  IP changed while up (DHCP lease change) both fire an "up" event; either way
  `firmware/code.py` restarts the HTTP server (`restart_http()`) on the current host
  address. This covers a listening socket gone stale on the old interface even
  when the IP didn't change, at the cost of one rebind (`adafruit_httpserver`
  4.x sets `SO_REUSEADDR`, so rebinding port 80 works).
- If all 6 reconnects fail, `firmware/code.py` calls `microcontroller.reset()`: the boot
  then fails the ~20 s join and falls back to the setup AP (§ AP mode above),
  which itself reboots to retry after `AP_IDLE_RETRY_S` idle. A long router
  outage becomes a bounded retry loop with an always-recoverable device.
- `server.poll()` is skipped entirely while the link is down (a dead socket
  would otherwise log an error every pass), and NTP / the ADS-B poll are
  gated the same way. The brightness schedule keeps running while offline.
- The web UI server is also restarted whenever it isn't running and the link
  is up (retried every 30 s), and after 5 consecutive `server.poll()`
  exceptions (a fresh start clears the counter). Both apply in AP mode too.
- Serial lines (the Wi-Fi password is never stored or printed):
  - `wifi: link lost (ip was X); first reconnect in 10 s`
  - `wifi: reconnect n/6 to SSID`
  - `wifi: reconnect n/6 failed: <err>`
  - `wifi: link up, ip X unchanged|(was Y) (<why>)`
  - `wifi: still down after 6 reconnects (N s); hard reset`

Known blocking: each reconnect attempt can block for up to 10 s (pausing the
dimmer schedule), and the UI is unreachable during an outage anyway.

## 8. On-device card assembly (was "Cloud API")

Superseded by issue #2: there is no server. `firmware/lib/net.py` (issue #26)
calls OpenSky's `/api/states/all` directly with the device's own bbox
(`firmware/lib/bbox.py`) and `extended=1`, then `firmware/lib/filters.py`,
`firmware/lib/hero.py`, and `firmware/lib/enrich.py` assemble a card with this
same shape on-device, in `firmware/code.py:poll_card()`, for `firmware/lib/card.py`
(issue #27, **to build**) to render. `route`/`type`/`city`/`phase` are not
populated yet -- nothing on-device currently supplies flight-route,
aircraft-type, or airport/phase data for a raw ADS-B state vector, only what
OpenSky itself sends (position/altitude/speed/track/category); they're left
`""` rather than invented, pending a real data source. `prefs.api`/`prefs.token`
(an OpenSky account, not a "cloud API" of ours) are only needed if OpenSky's
anonymous rate limit proves too low in practice; `prefs.token`, when set, is
sent as `Authorization: Bearer <token>`.

Card shape (assembled on-device, not an HTTP response):

```json
{
  "ok": true,
  "flight": "ASA331",
  "airline": "Alaska",
  "logo": "asa",
  "route": "PDX-LAX",
  "type": "737 MAX 9",
  "city": "Portland Intl",
  "phase": "arriving",
  "alt": 11200,
  "spd": 342,
  "track": 175,
  "hex": "a1b2c3",
  "age_s": 8
}
```

Empty sky: `ok: true`, `flight: null`.  
Fetch failure (OpenSky unreachable, rate-limited, or malformed response):
`firmware/lib/net.py` returns `None`/raises rather than an HTTP error code; `firmware/lib/hero.py`
treats a failed poll as "no fresh candidates" (see `Hero.expired()`), not as
"the hero left the box".

Hero aircraft selection (on-device, `firmware/lib/hero.py`; see issue #2 — the S3 calls
OpenSky directly, so this runs on-device instead of on the server as originally
sketched here):

1. Positions in bbox, airborne (`on_ground` false); `firmware/lib/hero.py:candidates()`
   turns the raw OpenSky state vectors into candidate dicts, skipping ground
   traffic, rows without a position, and malformed rows.
2. Apply hide_* filters (`firmware/lib/filters.py:apply()`, on-device, issue #2; a
   filtered-out hero is treated as rule (b), "gone")
3. Prefer closest to pin; tie-break lower altitude then higher speed
   (`firmware/lib/hero.py:_rank`)
4. Enrich hex → type/reg; callsign prefix → airline + badge id (`firmware/lib/enrich.py:lookup()`,
   on-device, issue #2); route cache → OD pair + city + arriving/departing if possible
5. If enrichment missing, still return callsign + alt + spd

**`extended=1` is required.** `firmware/lib/net.py`'s OpenSky request must add
`&extended=1`, or every state vector's category comes back `None`: helicopters
are never detected (`firmware/lib/filters.py:is_heli()` only matches category 8) and
`is_ga()` falls back to the callsign-shape heuristic for everything.

**Hysteresis / hold** — the shown aircraft is tracked by ICAO hex and only
changes when one of these fires (`firmware/lib/hero.py:select()`, called each poll by
the `Hero` class):

- **(a) Closer.** A challenger must be at least 20 % closer *and* at least
  0.5 mi closer than the current hero, and the current hero must have been
  shown for at least 30 s (`SWITCH_RATIO`, `MIN_GAP_MI`, `MIN_DWELL_S`).
  - 20 %: at 15 s polls a jet at ~250 kt covers ~1.2 mi/poll; in a 10 mi box,
    20 % of a typical 5 mi distance is ~1 mi, comfortably above OpenSky's
    position-delay jitter (~0.3–0.4 mi), so noise alone can't trigger a swap.
  - Swapping back needs the old hero to become ~36 % closer than it was,
    which takes real movement, not noise — so a switch does not bounce back.
  - 0.5 mi minimum: near the pin, 20 % is smaller than position noise, so an
    absolute floor is also required.
  - 30 s = two polls at the 15 s poll interval, so the card stays up long
    enough to read; it has no effect once polls are >= 30 s.
- **(b) Gone.** The hero's hex is absent from a *successful* OpenSky
  response: it left the box, landed (`on_ground`), was filtered out, or went
  out of coverage.
- **(c) Too old.** Limit is `3 * poll_s`, clamped to 30–90 s (45 s at the
  current 15 s poll interval; `firmware/lib/hero.py:stale_limit()`). Either:
  - the position in the data is too old (response `time` minus
    `time_position`, or `last_contact` when that's missing), or
  - no successful poll has confirmed the hero within that limit
    (`Hero.expired(now)`, for repeated fetch failures).
  - The 90 s cap exists because a plane at 250 kt moves ~6 mi in 90 s, past
    which the card would be misleading.

When there is no current hero, the closest candidate is picked (same
tie-break as above). Distances are statute miles, matching `firmware/lib/bbox.py`
(69 mi/degree) and the prefs `nm` field, which despite its name is also miles
each way.

### Badges (was `GET /v1/logo/{id}`)

Superseded (issue #2): airline badges are no longer fetched from the cloud;
everything below is baked into `firmware/lib/logos/<key>.bmp` at build time, one file
per `firmware/lib/enrich.py:AIRLINES` entry plus a generic fallback (`_unk.bmp`), all
4-bit indexed BMP (`adafruit_imageload.load()` / `displayio.OnDiskBitmap()`,
one badge in RAM at a time). No PNG, no network round-trip, no server.

Two build tools produce `firmware/lib/logos/`, and both can coexist:

- `tools/gen_badges.py` (host-only, stdlib-only, Pillow-free): draws
  non-trademarked 24×24 letter-mark badges (IATA/ICAO code, hand-drawn 3×5
  font, 3-color palette — index 0 black, 1 tile background, 2 mark color;
  354 bytes each). This is every airline's badge by default and remains the
  fallback for any airline the next tool hasn't covered.
- `tools/convert_logos.py` (host-only, needs Pillow + cairosvg for SVG
  sources — issue #18): converts a real sourced logo image
  (`tools/logo_sources/<key>.{svg,png,...}`) into the same BMP container,
  fit to its own aspect ratio (longest side ≤ 48 px, the sec. 9 slot budget,
  not forced square), with an 8-color palette lerped from black (index 0) to
  that airline's existing `AIRLINES` accent color (index 7) instead of the
  source's own brand color — several official brand hex values (UPS's,
  Lufthansa's) are near-black and unreadable against the panel's black
  background, while `AIRLINES`'s colors were already picked to be legible
  there. The extra palette steps (vs. the letter-mark's 3) are what keep a
  logo's thin strokes and antialiasing from collapsing into a blob at this
  size; `firmware/lib/dim.py`'s `scale_palette()` rescales a palette of any length the
  same way, so night-mode dimming needs no changes for either badge type.

Priority is automatic and needs no runtime code: `firmware/lib/enrich.py:badge_path()`
is a direct `firmware/lib/logos/<key>.bmp` path lookup with no separate resolution
step, so whichever tool last wrote that file is what loads. The two tools
stay consistent via `tools/logo_sources/sources.json`, a manifest
`{icao: source_filename}` that `convert_logos.py` writes and `gen_badges.py`
reads (`real_logo_keys()`) so that re-running `gen_badges.py` alone never
overwrites or prunes a real logo — it just skips those keys. Re-running
`convert_logos.py` (`--dir tools/logo_sources`) after `gen_badges.py` is what
actually re-asserts a real logo's priority if a key's letter-mark badge was
ever regenerated in between.

As of this writing, 49 of the 49 `AIRLINES` entries have a real logo. 13 of
the initial issue #18 pass (American, United, Southwest, JetBlue, FedEx, UPS,
Air Canada, British Airways, Lufthansa, KLM, Emirates, Qatar Airways, Turkish)
came from Simple Icons (CC0-licensed simplified brand marks,
`cdn.jsdelivr.net/npm/simple-icons`) and go through `convert_logos.py`'s
silhouette mode (single-color glyph, tinted to the `AIRLINES` accent). The
remaining 36 (the initial pass's Air France and Delta, plus the 34 sourced
afterward: Alaska, Spirit, Frontier, Allegiant, Hawaiian, Sun Country, Avelo,
Breeze, SkyWest, Envoy, Republic, Endeavor, PSA, Mesa, Horizon, Piedmont,
GoJet, Air Wisconsin, CommutAir, Cape Air, Atlas Air, ABX Air, ATI, Kalitta,
Polar Air Cargo, Amerijet, Omni Air Intl, National, NetJets, Flexjet, WestJet,
Aeromexico, Viva Aerobus, Volaris) came from `img.logo.dev/<domain>?format=png`
(a per-carrier domain lookup, using
logo.dev's publishable demo token documented on their own site — no account
of ours) and go through the *photo* mode instead: these are raster marks
that carry their own real brand colors, so (unlike the silhouette batch)
they keep the source's colors rather than the `AIRLINES` accent tint. This
is the first real exercise of `convert_photo()`; its docstring's "no such
source is committed yet" is now stale. Every domain was verified to actually
resolve to that airline's own site (or logo.dev's cached asset for it)
before use — three of the issue's guessed domains turned out wrong or dead
and were swapped for the real one: Omni Air International's actual site is
`oai.aero`, not `omniairintl.com` (parked/IIS-default); National Airlines
(N8/NCR)'s is `nationalairlines.com`, not `nationalair.com` (a same-named,
unrelated business); ATI/Air Transport International (8C/ATN)'s is
`airtransport.cc`, not `atiacmi.com` (unreachable) or the `atiaviation.com`
near-miss (a different, unrelated "ATI Aviation Services"). Horizon Air's
`horizonair.com` legitimately resolves to the same Alaska Airlines "Eskimo"
mark Alaska itself uses — Horizon retired its independent brand in 2011 and
now flies co-branded as "Alaska Horizon" — so reusing that art for `qxe` is
correct, not a scraping error.

Air France and Delta moved from the initial Simple Icons pass to
logo.dev/photo mode on a later review of all 15 (user-flagged). Two distinct
problems turned up, and the same review deliberately checked all 15 against
both, not just re-examining the one flagged carrier:

- **Wrong mark**: Simple Icons' `afr.svg` was just the loose diagonal accent
  slash with no wordmark or color cue, tinted to a plain blue that doesn't
  match Air France's actual red/navy branding — on its own it didn't read as
  Air France's mark at all. `airfrance.com`'s logo.dev fetch (the same slash
  plus the "AIRFRANCE" wordmark, in the airline's real red) replaced it; the
  wordmark all but disappears at the 48 px badge size (it's a thin,
  small-relative-to-the-icon typeface that photo mode's 8-step quantizing
  washes out — a known photo-mode limitation, see `convert_photo()`'s
  docstring), but the red slash alone is already a correct, recognizable
  improvement over the old shape and color.
- **Wordmark lockup squeezed illegible**: silhouette mode fits a source to
  its own aspect ratio at longest-side-48px, so a *wide* source — a full
  wordmark, or a wordmark+icon lockup — collapses to a sliver instead of
  shrinking evenly. Simple Icons' `dal.svg` is Delta's full "DELTA" wordmark
  next to the widget triangle, which came out **48×8px**: five letters in an
   8px-tall strip, illegible on the actual LED panel regardless of how
  accurate the shapes are. `delta.com`'s logo.dev fetch is the widget
  triangle alone (no wordmark) and converts at a proper 48×48 — that
  replaced it.

The other 13 Simple Icons silhouettes were checked the same way — rendered
against a logo.dev fetch of the same airline, and their badge's actual output
aspect ratio/height checked as a fast signal for a hidden wordmark-lockup
problem (the `dal` failure mode: a single-digit output height from a source
with letterforms in it). None of the other 13 have that shape (heights range
28–48px; the two shortest, FedEx at 13px and JetBlue at 16px, are inherently
wordmark-only brands with no separate icon mark to substitute, and both are
still legible at that height — nowhere near `dal`'s 8px). All 13 were judged
fine as plausible, correctly-shaped, legible versions of the real mark and
left untouched. All 49 files together are a little over 50 KB; on the
board's 512-byte FAT clusters that's comfortably inside the 8 MB flash.

One more carrier was swapped after this review: `swa` (Southwest) was still
on its Simple Icons silhouette (a monochrome heart, tinted to Southwest's
`AIRLINES` yellow) because logo.dev's fetch for `southwest.com` came back
bad/near-blank. Wikimedia Commons — a 403/rate-limited dead end during the
original 34-carrier sourcing push — was reachable on a later attempt and had
Southwest's real 2014-logo SVG, which turned out to have the tri-color heart
(blue/red/yellow gradient triangles) as separate `<path>` elements from the
"Southwest" wordmark text; cropping to just the heart paths gave a real,
correctly-colored icon-only mark instead of another wordmark-lockup risk.
It needed two things the pipeline didn't have yet: forcing "photo" mode on
an `.svg` source (detect_mode() assumes `.svg` means the single-color
silhouette path, wrong here since this source keeps its own 3 brand colors),
and 16 palette steps instead of the default 8 (the gradient's yellow/orange
end washed out to a muddy tan at 8 — median-cut quantization needs the extra
resolution when a small-area color region has to share the palette with two
much larger ones). Both are now first-class: `convert_logos.py --mode/--steps`
flags, and `tools/logo_sources/sources.json` entries can be either a bare
filename (the common case, mode/steps both default) or
`{"file": ..., "mode": ..., "steps": ...}` when a source needs an override —
recorded automatically the first time it's given one, so a later plain
`--dir` re-run reproduces it without repeating the flags.

Sources tried that did *not* pan out, for the next carrier that needs one:
Simple Icons only covers the first 15 (it's a general tech/consumer brand
set, not an airline-specific one — none of the remaining 34 appear in it);
`github.com/gilbarbara/logos` is the same kind of tech-brand set and has no
airline matches either; `worldvectorlogo.com` 403s every page (search and
logo, several query shapes tried, several browser user-agents) behind a
Cloudflare bot challenge; `svgrepo.com` 403s behind a Vercel bot checkpoint;
`cdn.brandfetch.io/<domain>` now 302-redirects to a "client ID required"
notice — the old unauthenticated quick-logo trick is dead; `img.logo.dev`
*without* a token 401s, but `?token=<their published demo token>&format=png`
works well and was this batch's actual source.

**Licensing**: this is the project owner's personal, non-commercial build
(issue #18). The owner has explicitly decided not to pursue trademark
clearance for shipping real airline logos on it, overriding sec. 2's
original "no airline trademark artwork" non-goal for this reason alone —
that is a stated project decision, not legal advice, and not something this
repo attempts to justify further. The letter-mark generator is kept
specifically so any fork or reuse that does care about that can drop back to
it (delete `tools/logo_sources/sources.json`, or the individual keys in it,
and re-run `tools/gen_badges.py`) without losing badge coverage for any
airline.

### Rate limits

No shared cache: each device polls independently with its own bbox (the two
owners' units are in different cities, so a shared cache never had a hit
anyway -- see issue #2). Do not call `states/all` without a bbox. Honor
OpenSky's rate limits and non-commercial terms; `prefs.token` (optional
OpenSky account credentials) raises the anonymous limit if needed. Badges
need no cache: they are static files already on the drive.

## 9. Firmware modules

| Module | Role | Status |
|---|---|---|
| `firmware/lib/prefs.py` | load/save/clamp/form merge | exists |
| `firmware/lib/sun.py` | sunrise/sunset | exists |
| `firmware/lib/schedule.py` | sleep/night/brightness | exists |
| `firmware/lib/bbox.py` | OpenSky box | exists |
| `firmware/lib/dim.py` | colour-scale dimming + sleep blank | exists |
| `firmware/lib/tz.py` | UTC offset + fixed US DST rule | exists |
| `firmware/lib/urldecode.py` | percent-decode form bodies | exists |
| `firmware/lib/buttons.py` | hold-to-trigger button helper | exists |
| `firmware/lib/nyan.py` | easter egg animation | exists |
| `firmware/lib/hero.py` | hero-aircraft selection + hysteresis (on-device, issue #2) | exists |
| `firmware/lib/enrich.py` | callsign → airline name + badge key/path, on-device (issue #2) | exists |
| `firmware/lib/filters.py` | on-device hide_heli / hide_mil / hide_ga (issue #2; §10) | exists |
| `firmware/www/index.html` | settings UI | exists |
| `firmware/code.py` | matrix, Wi-Fi join / setup-AP fallback, station reconnect watchdog, web UI server (auto-restart), NTP, dimmer schedule; poll_card() wires firmware/lib/net.py → filters → hero → enrich into a real card (issue #26) | exists |
| `firmware/lib/linkwatch.py` | station Wi-Fi drop detection, bounded reconnect (6 tries, ~4 min), then hard reset into setup AP | exists |
| `firmware/lib/httpclient.py` | shared adafruit_requests Session, 4 s timeout, 8 s/32 KB body cap, always-close get_json() for firmware/lib/net.py | exists |
| `firmware/lib/captiveportal.py` | AP-mode captive-portal DNS responder (issue #21; §7 AP mode) | exists |
| `firmware/lib/card.py` | render 128×64 card | **to build** (issue #27) |
| `firmware/lib/net.py` | HTTPS GET nearby, extended=1, optional bearer token (§8; issue #26) | exists |

### Display card (128×64)

Layout (pixel budget):

```
+------------------+----------------------------+
| up to 48×48      | Airline                     |
| badge            | FLIGHT  ROUTE               |
+------------------+ TYPE                        |
| city / phase                               |
| ALT  SPD  TRK                              |
+--------------------------------------------+
```

- Badge: local `firmware/lib/logos/<key>.bmp`, loaded via `adafruit_imageload.load()`
  or `displayio.OnDiskBitmap()` (§8, issue #2). Up to **48×48**: a real
  sourced carrier logo (`tools/convert_logos.py`, issue #18) where one exists
  (49/49 `AIRLINES` entries, as of this writing), else a generated 24×24
  letter-mark (`tools/gen_badges.py`) — still the fallback for the generic
  `_unk` badge and for any airline added to `AIRLINES` before a real logo is
  sourced for it. See §8 Badges for the licensing note and how the two
  coexist. Register
  one badge palette in `firmware/lib/dim.py` and overwrite its colours on each hero
  swap (`Dimmer.add_palette` only ever adds, so swapping badges by adding a
  fresh palette every poll would leak memory) — note a real logo's palette
  is longer (8 entries) than a letter-mark's (3), so this still-to-build
  wiring needs to size that registered palette to the badge actually loaded
  (e.g. re-registering per swap) rather than assume a fixed length
- Font: `terminalio.FONT` or a bundled 5×7 / 6×12 bitmap font
- Colors: white text, dim gray labels, badge as-is
- Sleep: empty group / brightness 0
- No data: `NO TRAFFIC` + local time
- Error: `NO LINK` (do not crash the HTTP server)

`bit_depth=4` (set via `BIT_DEPTH` in `firmware/code.py`); 3 gives only 7 lit levels per channel. Do not use 6+ for MVP.

### Poll loop

- `server.poll()` every iteration
- ADS-B poll every 15 s when not sleeping
- Outbound HTTP only via `firmware/lib/httpclient.py` (4 s per-socket-op timeout, 8 s body budget, response always closed; worst-case stall ~16 s); keep last good card
- Skip NTP/poll and `server.poll()` while `LinkWatch` reports the link down
- Never block the UI server for more than one poll

## 10. Filters

On-device (`firmware/lib/filters.py`, issue #2 — no server blocklist). Heuristic MVP,
documented as imperfect:

- **Helicopter (`is_heli`):** true only when OpenSky's ADS-B emitter
  `category == 8` (Rotorcraft). This field is state-vector index 17 and is
  only populated when the `/states/all` request includes `&extended=1`
  (`firmware/lib/net.py`, issue #26) — without it every category is `None` and no
  helicopter is ever detected. Category values: 0 no info, 1 no category info,
  2 Light, 3 Small, 4 Large, 5 High Vortex, 6 Heavy, 7 High Perf, 8 Rotorcraft,
  9 Glider, 10 Lighter-than-air, 11 Parachutist, 12 Ultralight, 14 UAV.
- **Military (`is_mil`):** the aircraft's ICAO 24-bit hex address against
  `MIL_RANGES`, a 32-entry table copied from readsb's `isMilRange()`
  (`wiedehopf/readsb` `aircraft.c`, commit 3b5368a — the same list tar1090
  uses), plus three US military callsign designators (`RCH`, `CNV`, `PAT`).
  The US range is `ADF7C8–AFFFFF`: US civil N-number registrations fill
  `A00001–ADF7C7` (N99999 = ADF7C7, 915,399 addresses), so everything above
  that in the US block is non-civil. Canada is `C20000–C3FFFF`. Known limit:
  the US range also holds some non-military federal aircraft.
- **GA (`is_ga`):** rules applied in order —
  1. Helicopter or military → not GA (keeps the three toggles independent).
  2. Callsign prefix in `firmware/lib/enrich.py:AIRLINES` → not GA (covers e.g. FedEx
     Caravan feeders, which fly as category 2 Light).
  3. Category 2, 9, 10, 11, 12, or 14 → GA.
  4. Category 4, 5, or 6 (airliner-sized) → not GA.
  5. Otherwise, GA only if the callsign is not airline-style (a bare tail
     number like `N123AB`, or no callsign at all).

  Known limit: a helicopter that never broadcasts a category shows as not a
  helicopter (falls through to the GA/airline heuristics instead).

`hidden(c, prefs)` returns `"heli"`, `"mil"`, `"ga"`, or `None`; `apply(cands,
prefs)` (used in the hero poll path, §8 step 2) returns the candidate list
unchanged when no filter is enabled. If `hide_ga` is true in a 10-mile
Magnolia box, the board may be empty often (Hooks GA). Default `hide_ga: false`.

## 11. Security

- No cloud tier, so no device/cloud token to manage (issue #2)
- Local UI has no auth in MVP (LAN trust). Do not expose the S3 port to WAN
- OpenSky token (optional, only to raise the anonymous rate limit) lives in `/prefs.json` on-device. It is write-only: `token` is never present in a `GET`/`POST` `/api/prefs` response, only a `token_set` boolean (`firmware/lib/prefs.py:public()`, `firmware/lib/reqguard.py`, issue #14)
- All `/api/*` routes require `Host` to match the device's own current address (blocks DNS rebinding); POSTs also require a same-origin `Origin` (or `Referer` if no `Origin`), or a `403` (blocks CSRF from another site the LAN browser has open) -- `firmware/lib/reqguard.py`, checked by `firmware/code.py:_guard()`
- CIRCUITPY is writable; do not put secrets in git

## 12. Implementation order (coding agent)

Do these PRs/slices in order. Each slice must run on hardware or have a clear mock.

1. ~~**Harden existing prefs + UI**~~ — done (issues #4, #5)
2. **Card renderer** — `firmware/lib/card.py`, hardcoded style card on 128×64 -- **to build** (issue #27)
3. ~~**Schedule live**~~ — done (issue #7); ~~**Brightness dimming**~~ — done (issue #8)
4. ~~**OpenSky HTTPS client**~~ — done (issue #26): `firmware/lib/net.py` hits OpenSky's `/api/states/all` directly with bbox + `extended=1`, optional bearer token; parses JSON via `firmware/lib/httpclient.py`
5. ~~**Lookup tables + badges**~~ — done (issue #10: `firmware/lib/enrich.py`, `firmware/lib/filters.py`, `firmware/lib/logos/`)
6. ~~**Hero selection**~~ — done (issue #9: `firmware/lib/hero.py`)
7. **AP fallback** — if no Wi-Fi (issue #11, in progress)
8. ~~**Wire it together**~~ — done for the data half (issue #26): `firmware/code.py:poll_card()` calls `firmware/lib/net.py` → `firmware/lib/filters.py` → `firmware/lib/hero.py` → `firmware/lib/enrich.py` and assembles a real card dict. Still missing `firmware/lib/card.py` (issue #27) to actually render it -- `code.py` prints the card to serial but the LED matrix still shows the placeholder group.

Do not start a rewrite in ESP-IDF unless CircuitPython HTTPS + HTTP server cannot coexist. If it cannot, port modules 1:1 to Arduino/ESP-IDF and keep this spec.

## 13. Acceptance tests

Host-side tests are plain Python 3 (stdlib only, no pytest) and are not copied
to CIRCUITPY. Run them all from the repo root:

```
for f in tests/test_*.py; do python3 "$f" || exit 1; done
```

`tests/test_code_*.py` run the real `firmware/code.py` under fake CircuitPython modules
(`board`, `wifi`, `displayio`, `adafruit_httpserver`, ...) with a simulated
clock: they check control flow and serial output, not the panel or the radio.

### 13.1 Automated (host-side)

| Behavior (spec §) | Test |
|---|---|
| Pin (lat/lon/nm) saved from the web form survives a fresh `load()` (the reboot); a second unit sets a different pin through the same code path, no firmware fork (§5, §6) | `tests/test_prefs.py` |
| `/prefs.bak` written on save and used when `/prefs.json` is corrupt; clamps: `nm` 1–50, brightness 0–1 and ≤ `brightness_max`, `tz_offset_min` −720..840, unknown `night_mode` → `sunset`, legacy `timezone` dropped; lat/lon/HH:MM fields validated with a default fallback (§6, issue #15) | `tests/test_prefs.py`, `tests/test_prefs_validation.py` |
| Form POST: missing checkbox = `false`; JSON POST: partial merge, booleans as-is, unparseable numbers / unknown keys ignored; write-only `token` merge rules (§6, issue #14) | `tests/test_prefs.py`, `tests/test_prefs_token.py` |
| Bbox matches the §6 formula (10 mi at 30N 95W; 5 mi friend pin); existing cos(lat) floor of 0.2 above ~78.5° | `tests/test_bbox.py` |
| Sleep window → brightness 0 (wraps midnight, end exclusive, start == end means off, CST and CDT) (§6 Schedule) | `tests/test_schedule.py` |
| Fixed night hours or after local sunset → night slider, capped by `brightness_max`; `night_mode=off` → day level; fixed US DST rule boundaries (§6 Schedule) | `tests/test_schedule.py` |
| Clock-trust gate: default-epoch RTC never blanks or night-dims; NTP-synced or ≥ 2024 RTC applies the schedule (§6, issue #11) | `tests/test_schedule_clock.py` |
| Dimmer: level 0 → blank group + `display.brightness = 0.0`; wake restores the awake group at 1.0; palettes rescaled from base colours (no compounding) with the min-visible floor (§6) | `tests/test_dim.py` |
| `firmware/code.py`: in a sleep window the panel level is 0.0 and no ADS-B poll runs; awake, the poll's bbox comes from the saved pin (§6, §9 Poll loop) | `tests/test_code_schedule.py` |
| `firmware/code.py` setup AP: no SSID → WPA2 `TailWatch-XXXX`, 8-char password from the 32-symbol alphabet, fresh each boot, printed once, quietest of channels 1/6/11, UI on 192.168.4.1, no NTP, stays up indefinitely; SSID configured but unreachable → two join attempts, AP, reboot after `AP_IDLE_RETRY_S` idle (§7 AP mode) | `tests/test_code_apmode.py` |
| `settings.toml` Wi-Fi writer: validation, form parsing, TOML escaping, other keys kept, crash-safe swap + `recover()` (§7 AP mode) | `tests/test_wifisettings.py` |
| `CaptiveDNS._build`: A/ANY query answered with the AP's IP, AAAA gets NOERROR/no-answer, malformed packets dropped, transaction ID echoed (§7 AP mode, issue #21) | `tests/test_captiveportal.py` |
| `firmware/code.py` AP mode: a DNS query fed to the poll loop gets answered with the AP's own IP; captive-check HTTP routes (`/generate_204`, `/hotspot-detect.html`, ...) registered only in AP mode (§7 AP mode, issue #21) | `tests/test_code_apmode.py` |
| LinkWatch: grace period, 6 bounded reconnects then give-up, self-recovery, IP change while up, radio errors count as down, password never printed (§7 Wi-Fi drop recovery) | `tests/test_linkwatch.py` |
| `firmware/code.py` link handling: drop + rejoin on a new IP moves the UI server; gives up → hard reset; 5 consecutive `server.poll()` errors restart the server; no `server.poll()` while down (§7 Wi-Fi drop recovery) | `tests/test_code_linkwatch.py` |
| Outbound HTTP: one Session reused, timeout passed, response always closed, non-200 + `Retry-After`, mid-body error, 8 s / 32 KB caps (§9 Poll loop) | `tests/test_httpclient.py` |
| Hero: candidate parsing (ground / no-position / malformed skipped; `states: null` → no candidates), closest + tie-break, hysteresis rules (a)(b)(c), no flapping, `Hero.expired()` (§8) | `tests/test_hero.py` |
| Filters heli / mil / GA and `apply()` on hero candidates; airline prefix lookup; badges committed, current, and decodable (§8 Badges, §10) | `tests/test_enrich_filters.py` |
| Local-UI same-origin guard: Host must match the device's address on every `/api/*` route; POSTs also require a same-origin Origin/Referer, else 403 (§11, issue #14) | `tests/test_reqguard.py` |
| `firmware/lib/net.py`: URL has the right path/bbox/`extended=1`, no token → no `Authorization` header, a token → `Bearer <token>` (stripped), a trailing slash on `prefs.api` doesn't double up, every `httpclient.get_json` failure (`HTTPStatusError` incl. `retry_after`, `OSError`/`RuntimeError`/`TimeoutError`/`ValueError`) propagates unchanged rather than getting swallowed (§8, issue #26) | `tests/test_net.py` |
| `firmware/code.py` real poll wiring: a real state vector becomes a card with the right flight/airline/logo/hex; empty sky → `flight: null`; a 429 backs off past its `Retry-After` (no poll fires early) and keeps the last good card; any other fetch failure also keeps the last good card without crashing the loop (§8, issue #26) | `tests/test_code_poll.py` |

### 13.2 Pending (blocked on unbuilt modules or open issues)

Add a host test for each item when its code lands, not before.

- **Empty sky → `NO TRAFFIC` + local time, not a crash.** Needs `firmware/lib/card.py`
  (§12 slice 2, issue #27). The data side is done: `tests/test_hero.py` (`states: null`
  → no candidates; `select(None, [])` → `(None, "none")`) and
  `tests/test_code_poll.py` (`poll_card()` returns `flight: None` on an empty
  response) both cover it up to the point nothing renders it yet.
- **OpenSky unreachable / 429 / malformed JSON → panel `NO LINK`, last good card
  kept, web UI still answers.** The data/backoff side is done (issue #26,
  `tests/test_net.py`, `tests/test_code_poll.py`); still needs `firmware/lib/card.py`
  (issue #27, §12 slice 2) to actually show `NO LINK` on the panel instead of
  just keeping `last_card` in memory.

### 13.3 Manual, on hardware only

- Power: full-white bench draw ~15 W @ 5 V from the panel PSU; USB-C powers
  only the S3; firmware never changes the power wiring (§3).
- From a phone on the same LAN, save lat/lon at `http://<s3-ip>/`, power-cycle,
  values persist (exercises `firmware/boot.py`'s read-write remount). Booted with UP
  held, a save returns 503.
- Sleep window: panel physically dark, serial shows no `hero`/card lines (no
  poll fires while asleep). The night level is visibly distinct from gray
  labels at `BIT_DEPTH = 4`.
- Setup AP: panel shows `WIFI SETUP` / `TailWatch-XXXX` / `pw …` /
  `192.168.4.1`; a phone joins with that password; "Save Wi-Fi & restart"
  joins the new network; wrong credentials come back up as the setup AP.
- Wi-Fi drop: reboot the router; serial shows `wifi:` lines and the UI is
  reachable at the (possibly new) IP afterward; an outage over ~4 min ends in
  a hard reset into the setup AP.
- Web Workflow off: no `CIRCUITPY_WEB_API_PASSWORD`; the UI binds port 80
  (no `http start failed`).
- After `firmware/lib/net.py` / `firmware/lib/card.py`: a real OpenSky poll returns categories
  (`extended=1`); card and badge are legible on the 128×64 panel; `NO LINK`
  with the uplink unplugged.

## 14. Repo / files

Only what is actually copied to the CIRCUITPY drive lives under `firmware/`
(`code.py`, `lib/`, `www/`, `settings.toml.example`, `prefs.example.json`).
Everything host-only -- build tools, tests, this spec -- lives at the repo
root instead.

```
firmware/code.py
firmware/settings.toml.example
firmware/prefs.example.json
firmware/www/index.html
firmware/lib/prefs.py
firmware/lib/sun.py
firmware/lib/schedule.py
firmware/lib/bbox.py
firmware/lib/dim.py
firmware/lib/hero.py
firmware/lib/enrich.py        # new (issue #2: on-device airline lookup)
firmware/lib/filters.py       # new (issue #2: on-device heli/mil/ga filters)
firmware/lib/logos/*.bmp       # new, generated (issue #2: on-device badges, not fetched;
                       #   issue #18: real logo where sourced, else letter-mark)
firmware/lib/card.py          # new (issue #27, to build)
firmware/lib/net.py           # new (issue #26)
firmware/lib/wifisettings.py  # new (issue #11: AP-mode settings.toml Wi-Fi writer)
firmware/lib/setupscreen.py   # new (issue #11: panel setup-AP credentials screen)
firmware/lib/linkwatch.py     # new (station Wi-Fi drop detection + bounded reconnect)
firmware/lib/httpclient.py    # new (shared, always-closing adafruit_requests client for firmware/lib/net.py)
firmware/lib/captiveportal.py # new (issue #21: AP-mode captive-portal DNS responder)
tools/gen_badges.py     # new, host-only (generates firmware/lib/logos/*.bmp letter-marks)
tools/convert_logos.py  # new, host-only (issue #18: real logos -> firmware/lib/logos/*.bmp)
tools/logo_sources/     # new (issue #18: sourced logo images + sources.json manifest)
tests/test_enrich_filters.py    # host-only
tests/test_hero.py              # host-only
tests/test_prefs.py             # host-only (prefs round trip, .bak, clamps, merge rules)
tests/test_prefs_validation.py  # host-only (issue #15: lat/lon/HH:MM validation)
tests/test_prefs_token.py       # host-only (issue #14: write-only token merge rules)
tests/test_reqguard.py          # host-only (issue #14: same-origin guard)
tests/test_bbox.py              # host-only (sec. 6 bbox formula)
tests/test_dim.py               # host-only (colour dimming + sleep blank)
tests/test_schedule.py          # host-only (sleep/night windows, US DST, sunset)
tests/test_schedule_clock.py    # host-only (issue #11 clock-trust gate)
tests/test_wifisettings.py      # host-only (issue #11)
tests/test_linkwatch.py         # host-only
tests/test_httpclient.py        # host-only
tests/test_code_linkwatch.py    # host-only (runs firmware/code.py with fake CircuitPython modules)
tests/test_code_schedule.py     # host-only (firmware/code.py sim: sleep skips poll, bbox from prefs)
tests/test_code_apmode.py       # host-only (firmware/code.py sim: setup-AP fallback, captive DNS + redirects)
tests/test_captiveportal.py     # host-only (issue #21: CaptiveDNS._build wire format)
tests/test_net.py               # host-only (issue #26: firmware/lib/net.py URL/auth/error propagation)
tests/test_code_poll.py         # host-only (issue #26: firmware/code.py sim, real net -> filters -> hero -> enrich wiring)
firmware/lib/reqguard.py      # new (issue #14: same-origin/CSRF guard)
DESIGN.md            # this file
README.md
```

## 15. Coding rules for the agent

- CircuitPython-compatible: no f-string heavy deps, no `pathlib` assumptions that fail on CP
- Avoid large allocations in the poll path
- Do not add Google/FlightRadar scraped APIs
- Do not commit tokens
- Match existing helper APIs rather than renaming without cause
- When unsure of MatrixPortal pin names, use `board.MTX_*` as in current `firmware/code.py`
- Update README with any new library bundle names

## 16. Reference context

- Product look: airline logo, flight number, city pair, aircraft type, arriving/departing city
- Open data: OpenSky Network state vectors in a bbox
- Enrichment later: FlightAware AeroAPI (paid, server-only)
- Starter firmware already serves `/api/prefs` and computes brightness/sleep/sunset

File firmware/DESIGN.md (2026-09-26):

# TailWatch — Design Document for Coding Agents

Status: implementable MVP  
Hardware target: Adafruit MatrixPortal S3 + indoor P2 SMD1515 128×64 HUB75 panel  
Companion: none -- the device calls OpenSky directly and assembles cards on-device (see issue #2; no cloud API)  
Existing starter: `firmware/` (`code.py`, `lib/*`, `www/index.html`, `prefs.example.json`)

This document is the spec. Do not invent product scope beyond it. Prefer small, working slices over frameworks.

---

## 1. Goal

A wall display that shows **one live aircraft card** for traffic near a user-configured GPS point, without requiring a subscription app.

Two physical units will exist (owner + friend). Each unit owns its own lat/lon and display prefs on-device, and assembles its own flight cards and badges locally (issue #2: no cloud tier). OpenSky (or compatible ADS-B) is the position source.

## 2. Non-goals (MVP)

- Multi-aircraft list or map on the LED panel
- On-device SQLite of the global fleet
- Captive-portal polish matching consumer routers
- Official airline trademark licensing (use simple letter marks / public-domain style sprites)
- Bonjour across the internet
- Driving more than one 128×64 panel
- Pi Pico / Pi Zero in v1 (allowed later; do not block S3-only path)

## 3. Hardware and power

| Piece | Spec |
|---|---|
| Controller | Adafruit MatrixPortal S3 (ESP32-S3, USB-C, HUB75, Wi-Fi) |
| Panel | P2-1515, 128×64, 256×128 mm, 1/32 scan, HUB75 |
| Panel power | External 5.0 V bench/PSU, **direct to the panel's own power input**, ~3 A measured full white (~15 W), budget 4–5 A |
| S3 power | USB-C only (board + logic) — its screw terminals are output-only, never a power input (see footgun below). Can share the panel's PSU via a second USB-C feed; do not wire the panel 5 V onto the S3's screw terminals |
| Wiring | HUB75 data from S3; panel 5 V/GND from PSU **wired to the panel itself**; common ground optional if noise appears |
| S3 power cable | Bare-wire-to-USB-C pigtail (5V, 3–5 A), spliced onto the same PSU as the panel rather than a second USB-C brick (see footgun note below) |

Firmware must never assume USB can power the LEDs.

**Known footgun (confirmed on hardware):** the MatrixPortal S3 has its own 5V/GND screw
terminals next to the HUB75 connector -- these are **output only**, wired straight to the
board's USB-C 5V rail, and exist so the board can drive a *small* panel with no external
supply at all. Landing the external PSU's barrel-to-terminal adapter on *those* terminals
instead of the *panel's own* power input looks correct but isn't: the panel ends up
entirely dependent on USB, and unplugging USB-C kills it even though a beefy external
supply is nominally connected. There is no actual backfeed in this case -- the panel
simply never had independent power. Always verify the PSU leads land on the panel's own
power pads/terminal, never the MatrixPortal's screw lugs.

**Powering both from one supply.** The S3's screw terminals being output-only doesn't
mean the board must run off a separate USB-C wall charger -- it means the board has to
be fed through its USB-C port specifically, same as always, just sourced from the same
PSU as the panel instead of a second brick. Land the PSU's 5V/GND leads on a small
junction (splice or terminal block) with two branches out of it: one straight to the
panel's own power input (as above, carries the bulk of the current), and one through a
**bare-wire-to-USB-C pigtail cable** into the MatrixPortal's USB-C port. That pigtail is
passive -- two wires to VBUS/GND, no PD negotiation -- so it presents the same fixed 5V
the board would see from any USB-C charger. Size the PSU for the panel's worst-case draw
plus the board's (well under 1A even with Wi-Fi active); the panel dominates the budget
either way. See the table above for a specific cable.

## 4. Architecture

```
[Phone browser]
    |  http://<s3-ip>/  or 192.168.4.1  (prefs only)
[MatrixPortal S3]
    |  lib/net.py: GET /api/states/all?lamin&lomin&lamax&lomax&extended=1
    |  (OpenSky token optional, only to raise the anonymous rate limit)
[OpenSky / ADS-B]
    + on-device lib/hero.py, lib/filters.py, lib/enrich.py, lib/logos/
```

No cloud tier (issue #2): each device polls OpenSky directly with its own
bbox and assembles/filters/enriches the card locally.

**On device (everything; no cloud copy of anything):** GPS, radius, brightness, sleep, night mode, filters, OpenSky token (optional), positions (fetched live, never persisted), enrichment tables, badges.

## 5. Device identity (two units)

- Each unit's `/prefs.json` (lat/lon, filters, OpenSky token) is entirely local -- nothing is shared or centrally stored, so there's no cross-device isolation to get wrong
- Same firmware image on both units
- Optional `device_id` printed on serial at boot for support

Provisioning MVP: owner pastes token + API URL in the local settings page. No account system required for two devices.

## 6. Preferences (on-device)

File: `/prefs.json` with `/prefs.bak` on write.

```json
{
  "lat": 30.0000,
  "lon": -95.0000,
  "nm": 10,
  "hide_heli": true,
  "hide_ga": false,
  "hide_mil": true,
  "brightness_day": 0.70,
  "brightness_night": 0.18,
  "brightness_max": 1.00,
  "night_mode": "sunset",
  "night_start": "21:00",
  "night_end": "06:30",
  "sleep_enabled": true,
  "sleep_start": "23:00",
  "sleep_end": "06:30",
  "tz_offset_min": -360,
  "us_dst": true,
  "api": "https://api.example.com",
  "token": ""
}
```

Rules:

- `nm` is miles **in each direction** (square bbox), clamp 1–50
- brightness fields 0.0–1.0; day/night clamped to `brightness_max`
- `night_mode`: `off` | `fixed` | `sunset`
- sleep and night mode are independent: sleep blanks the panel; night only dims
- booleans from HTML checkboxes: missing key on POST means `false`
- JSON POSTs are partial merges: omitted keys (including booleans) keep their stored value; JSON booleans are used as-is
- `tz_offset_min` + `us_dst` used for sleep/fixed night windows (lib/tz.py, fixed US DST rule only); sunset uses lat/lon solar math (UTC timestamps)

Apply prefs immediately on save except Wi-Fi credentials (Wi-Fi stays in `settings.toml` for MVP).

### Bounding box

```
dlat = nm / 69.0
dlon = nm / (69.0 * cos(lat_rad))
lamin, lamax = lat ± dlat
lomin, lomax = lon ± dlon
```

Existing helper: `lib/bbox.py`.

### Schedule

Existing helpers: `lib/sun.py`, `lib/schedule.py`.

Every ~1 s (or on prefs save):

1. If sleep window → `display.brightness = 0`, skip network poll
2. Else if night → `min(brightness_night, brightness_max)`
3. Else → `min(brightness_day, brightness_max)`

Dimming is done by scaling draw colours (`lib/dim.py` Dimmer). `display.brightness` is on/off on rgbmatrix, so it stays 1.0 while awake and 0.0 only for the black sleep state (blank group).

NTP at boot (UTC into RTC). The RTC and `sun.py` stay UTC. `schedule.py` computes local time as UTC + `tz_offset_min` (+60 min under the fixed US DST rule when `us_dst`) via `lib/tz.py`. No tz database: only the fixed US rule is supported.

**Clock-trust gate (issue #11).** NTP can fail (no internet yet, AP mode, a
flaky router), and after `microcontroller.reset()` the RTC may hold either a
real time it kept across the reset, or CircuitPython's built-in epoch
(commonly 2000-01-01). `lib/schedule.py:clock_trusted(ts=None)` returns true
if NTP has synced this boot (`set_clock_synced(True)`, called by `code.py`'s
`sync_clock()`), or if `ts` (default `time.time()`) is already
`>= MIN_TRUSTED_TS` (2024-01-01T00:00Z) -- the RTC-survived-reset case.
`sleeping()` and `night()` return `False` when the clock isn't trusted
(never blank the panel or apply night dimming on a bogus timestamp);
`brightness()` then falls through to `min(brightness_day, brightness_max)`.
`GET /api/status` exposes both `clock_synced` and `clock_trusted` so the web
UI can show a "clock not set" banner.

## 7. Local web UI

Static files in `/www`. Server: `adafruit_httpserver` on port 80. Web Workflow
(CIRCUITPY_WEB_API_PASSWORD) must stay disabled -- it also binds port 80 and
exposes the filesystem.

| Route | Method | Purpose |
|---|---|---|
| `/` | GET | `www/index.html` |
| `/api/prefs` | GET | current JSON minus `token`, plus `token_set` (`lib/prefs.py:public()`) |
| `/api/prefs` | POST | form or JSON merge → save → apply brightness (station mode only) |
| `/api/status` | GET | `{mode, ip, ssid, ap_ssid, networks, clock_synced, clock_trusted, rebooting, wifi_drops}` -- never a password |
| `/api/wifi` | POST | JSON or form `{ssid, password, open}` → `lib/wifisettings.py` → `/settings.toml` → hard reset (§ AP mode below) |

All `/api/*` routes require `Host` to be the device's own current address;
POSTs also require a same-origin `Origin`/`Referer`, else `403` (`lib/reqguard.py`,
issue #14). Reaching the UI by a DNS name instead of its IP therefore returns
403 on every `/api/*` call -- the UI is documented as `http://<ip>/`, not a
hostname.

UI fields must match the schema in §6 (already drafted in `www/index.html`).

MVP discovery: print IPv4 on serial and on the LED (`SETUP 192.168.x.x`) if no card yet. mDNS `tailwatch.local` is a stretch goal (CircuitPython support is uneven).

### AP mode (first boot, issue #11)

If `CIRCUITPY_WIFI_SSID` is empty, or joining it fails (two 10 s
`wifi.radio.connect()` attempts, ~20 s total):

- Scan for nearby networks first (`wifi.radio.start_scanning_networks()`,
  before `stop_station()` -- the radio can't scan once it's AP-only), for the
  UI's SSID datalist and to pick whichever of channels 1/6/11 has the fewest
  networks.
- Start a **WPA2, password-protected** AP `TailWatch-XXXX` (last two MAC
  bytes), `wifi.radio.start_ap(ssid, pw, channel=…, authmode=[WPA2, PSK],
  max_connections=2)`. The password is 8 random characters from a 32-symbol
  alphabet (no `l`/`o`/`0`/`1`), generated fresh every boot with
  `os.urandom`, never persisted, and only shown on the panel (and serial) --
  not open, because `POST /api/wifi` can repoint the device at another
  network, so being able to read the password proves you're standing at
  the device.
- Serve the same UI at `wifi.radio.ipv4_address_ap` (normally
  `192.168.4.1`); the Wi-Fi form is shown above the regular prefs form.
- Prefs save still writes `/prefs.json`, but the dimmer/brightness path is
  skipped in AP mode (`display.brightness = 1.0`, fixed `0x707070` setup
  text via `lib/setupscreen.py`, so a slider at 0 or a sleep window can't
  hide the password).
- No NTP attempt in AP mode (there is no internet).
- `POST /api/wifi` is the **only** allow-listed `settings.toml` writer
  (`lib/wifisettings.py`): it reads just `ssid`, `password`, `open` from the
  body (JSON or form; the body parser never reads the query string for this
  route, so a password can't leak into a URL/log), validates them, and
  rewrites just the two `CIRCUITPY_WIFI_*` keys via a `.new` →
  `path`↔`.bak` → rename swap (crash-safe; `recover()` finishes an
  interrupted swap on the next boot). Everything else in `settings.toml` is
  kept, and the previous file survives as `settings.toml.bak`. Wi-Fi is
  deliberately **not** part of the `/prefs.json` schema (§6).
  - On success: `{ok, ssid, rebooting: true}`, then
    `microcontroller.reset()` about 3 s later (after the reply flushes).
    The hard reset re-runs `boot.py` (remounts read-write) and the
    CircuitPython supervisor, which re-reads `settings.toml` and auto-joins;
    if the new credentials are wrong the device comes back up as the setup
    AP, so there's always an in-field recovery path.
  - `ValueError` (bad SSID/password) → 400 with the message; `OSError`
    (booted with UP held, filesystem read-only) → 503, same pattern as
    `/api/prefs`, and the device does not reboot.
- **Idle retry.** If an SSID *is* configured (e.g. the router was
  rebooting), the device reboots to retry the join after 600 s with no
  `/api/*` request. The setup page polls `/api/status` every 60 s while in
  AP mode, which keeps the device up while someone has it open. With no
  SSID configured at all, the device stays in AP mode indefinitely.

Hold BOOT 5 s to clear Wi-Fi settings is a stretch goal.

**Captive-portal auto-pop (issue #21).** A plain setup AP with no DNS/HTTP
tricks leaves a joining phone/laptop's own network stack unable to tell
there's anything to sign in to -- its captive-portal detection probes just
time out (AP mode has no internet to resolve or reach anything real), so the
OS never auto-launches a sign-in browser and the user has to already know to
browse to `192.168.4.1`. Two pieces make that auto-pop instead, both AP-mode
only:

- **DNS hijack** (`lib/captiveportal.py`, `CaptiveDNS`): a UDP responder
  bound to `:53` on the AP-mode `socketpool.SocketPool`, polled once per main
  loop tick (`captive_dns.poll()`, non-blocking). It answers every class-IN
  A or ANY query with the AP's own IPv4 address, and every other query type
  (AAAA, HTTPS/SVCB, ...) with a NOERROR/no-answer reply so the resolver
  falls through to an A query instead of stalling. It is not a general
  resolver -- there's nothing upstream to forward anything to -- and drops
  anything malformed or multi-question rather than guess at it. This is what
  makes the OS's captive-portal probe hostnames (e.g. Apple's
  `captive.apple.com`) resolve to this device at all.
- **HTTP redirects for the known OS probe paths** (`code.py`,
  `CAPTIVE_CHECK_PATHS` / `captive_redirect`): Android (`/generate_204`,
  `/gen_204`), Apple (`/hotspot-detect.html`,
  `/library/test/success.html`), Windows (`/connecttest.txt`, `/ncsi.txt`,
  `/redirect`), and Firefox (`/success.txt`), registered only
  `if ap_mode`. Each OS actually expects one specific "you have real
  internet" response (Android: bare 204; Apple: one exact HTML string;
  Windows: specific plain-text bodies) and treats *anything else* as "there's
  a portal here" -- so a redirect to `http://<host>/` is enough to trigger
  that path; trying to instead mimic each OS's exact expected success body
  would be more code for the same result and would have to be kept in sync
  with OS behavior that can change.

Together: DNS hijack gets the probe request to this device; the redirect
response is what makes the OS conclude a portal is present and open its
sign-in browser to it.

### Wi-Fi drop recovery (station mode)

Once joined as a station, `lib/linkwatch.py:LinkWatch` (`code.py`, station mode
only; `link = None` in AP mode) watches for a dropped link and re-joins it,
because CircuitPython's own retries are limited and `adafruit_httpserver`
otherwise keeps a listening socket bound to the address that just went away:

- Checks `wifi.radio` every 2 s. A drop waits 10 s (grace period, so
  CircuitPython's own few retries can run first), then makes up to 6
  reconnect attempts with gaps 10 / 20 / 30 / 60 / 60 / 60 s between them (about
  4 minutes total from the drop).
- Recovered (its own `connect()`, or the radio recovering on its own) or the
  IP changed while up (DHCP lease change) both fire an "up" event; either way
  `code.py` restarts the HTTP server (`restart_http()`) on the current host
  address. This covers a listening socket gone stale on the old interface even
  when the IP didn't change, at the cost of one rebind (`adafruit_httpserver`
  4.x sets `SO_REUSEADDR`, so rebinding port 80 works).
- If all 6 reconnects fail, `code.py` calls `microcontroller.reset()`: the boot
  then fails the ~20 s join and falls back to the setup AP (§ AP mode above),
  which itself reboots to retry after `AP_IDLE_RETRY_S` idle. A long router
  outage becomes a bounded retry loop with an always-recoverable device.
- `server.poll()` is skipped entirely while the link is down (a dead socket
  would otherwise log an error every pass), and NTP / the ADS-B poll are
  gated the same way. The brightness schedule keeps running while offline.
- The web UI server is also restarted whenever it isn't running and the link
  is up (retried every 30 s), and after 5 consecutive `server.poll()`
  exceptions (a fresh start clears the counter). Both apply in AP mode too.
- Serial lines (the Wi-Fi password is never stored or printed):
  - `wifi: link lost (ip was X); first reconnect in 10 s`
  - `wifi: reconnect n/6 to SSID`
  - `wifi: reconnect n/6 failed: <err>`
  - `wifi: link up, ip X unchanged|(was Y) (<why>)`
  - `wifi: still down after 6 reconnects (N s); hard reset`

Known blocking: each reconnect attempt can block for up to 10 s (pausing the
dimmer schedule), and the UI is unreachable during an outage anyway.

## 8. On-device card assembly (was "Cloud API")

Superseded by issue #2: there is no server. `lib/net.py` (to build) calls
OpenSky's `/api/states/all` directly with the device's own bbox (`lib/bbox.py`)
and `extended=1`, then `lib/hero.py`, `lib/filters.py`, and `lib/enrich.py`
assemble a card with this same shape on-device, for `lib/card.py` to render.
`prefs.api`/`prefs.token` (an OpenSky account, not a "cloud API" of ours) are
only needed if OpenSky's anonymous rate limit proves too low in practice.

Card shape (assembled on-device, not an HTTP response):

```json
{
  "ok": true,
  "flight": "ASA331",
  "airline": "Alaska",
  "logo": "asa",
  "route": "PDX-LAX",
  "type": "737 MAX 9",
  "city": "Portland Intl",
  "phase": "arriving",
  "alt": 11200,
  "spd": 342,
  "track": 175,
  "hex": "a1b2c3",
  "age_s": 8
}
```

Empty sky: `ok: true`, `flight: null`.  
Fetch failure (OpenSky unreachable, rate-limited, or malformed response):
`lib/net.py` returns `None`/raises rather than an HTTP error code; `lib/hero.py`
treats a failed poll as "no fresh candidates" (see `Hero.expired()`), not as
"the hero left the box".

Hero aircraft selection (on-device, `lib/hero.py`; see issue #2 — the S3 calls
OpenSky directly, so this runs on-device instead of on the server as originally
sketched here):

1. Positions in bbox, airborne (`on_ground` false); `lib/hero.py:candidates()`
   turns the raw OpenSky state vectors into candidate dicts, skipping ground
   traffic, rows without a position, and malformed rows.
2. Apply hide_* filters (`lib/filters.py:apply()`, on-device, issue #2; a
   filtered-out hero is treated as rule (b), "gone")
3. Prefer closest to pin; tie-break lower altitude then higher speed
   (`lib/hero.py:_rank`)
4. Enrich hex → type/reg; callsign prefix → airline + badge id (`lib/enrich.py:lookup()`,
   on-device, issue #2); route cache → OD pair + city + arriving/departing if possible
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

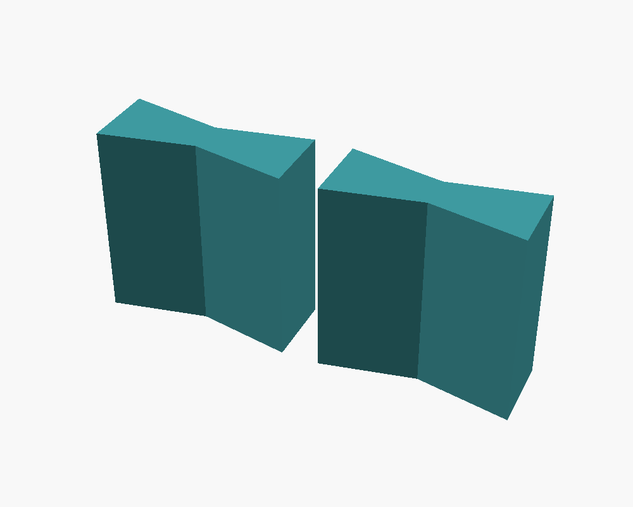
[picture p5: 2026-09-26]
enclosure/preview/bowtie_keys.png

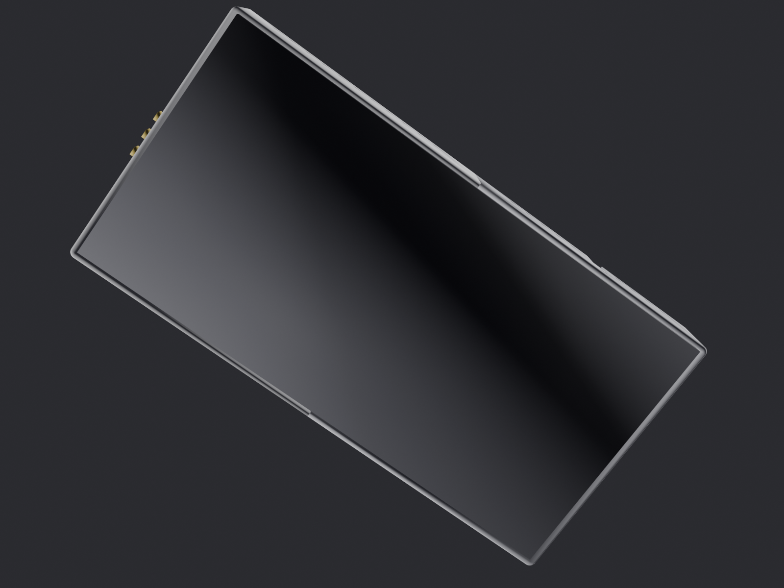
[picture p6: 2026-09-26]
enclosure/preview/blender_front.png

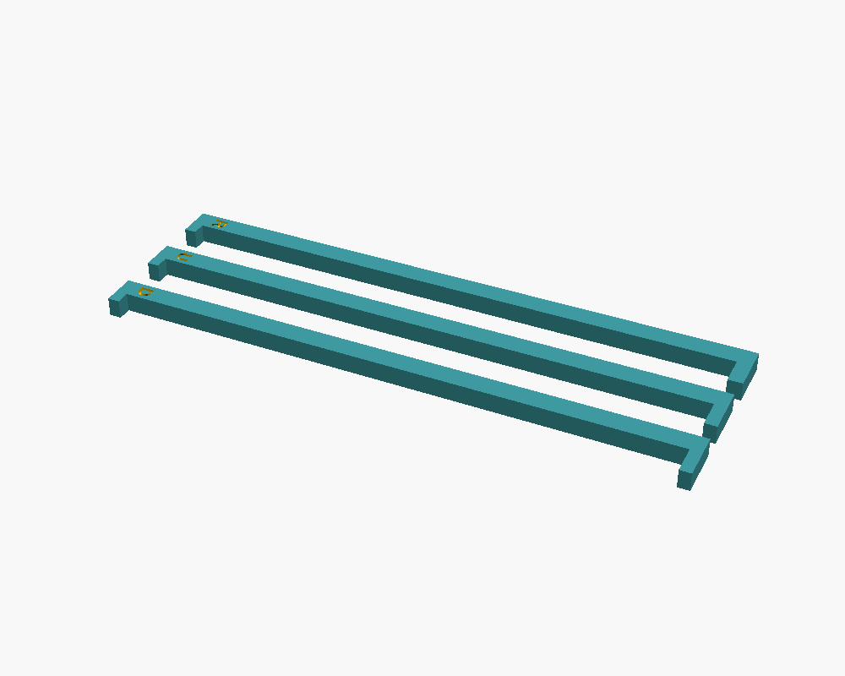
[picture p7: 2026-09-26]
enclosure/preview/button_rods.png

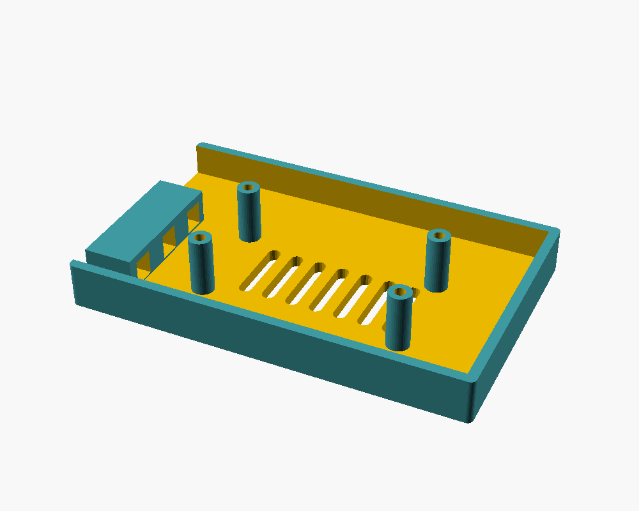
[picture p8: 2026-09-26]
enclosure/preview/portal_pod.png

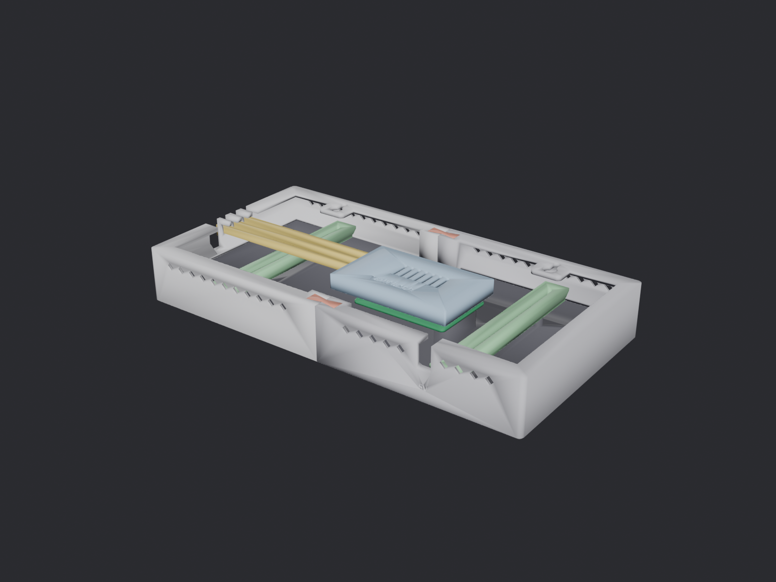
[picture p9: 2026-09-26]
enclosure/preview/blender_iso.png

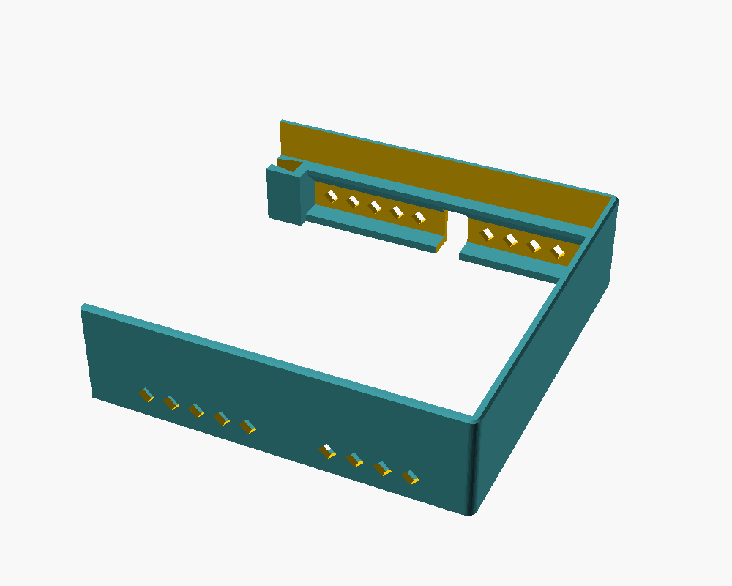
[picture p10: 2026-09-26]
enclosure/preview/frame_right.png

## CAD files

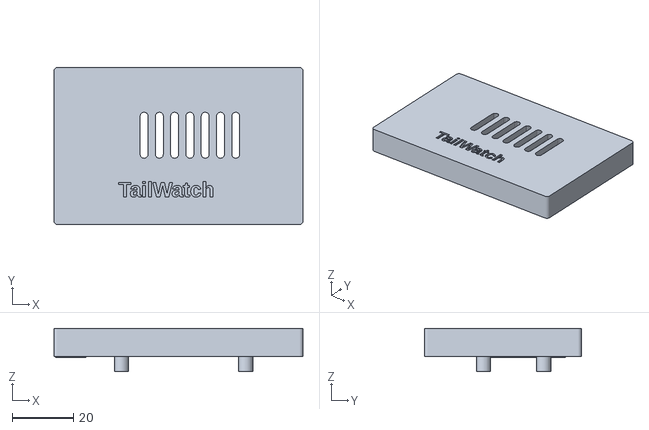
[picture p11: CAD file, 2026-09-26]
enclosure/blender_import/portal_pod.stl
81.5 x 51.4 x 14.2

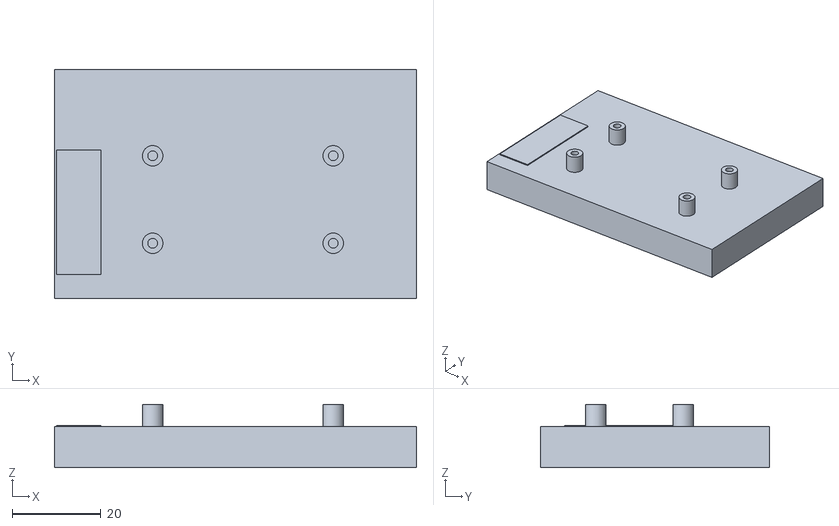
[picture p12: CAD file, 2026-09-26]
enclosure/step/portal_pod_cq.stl
81.5 x 51.5 x 14.2

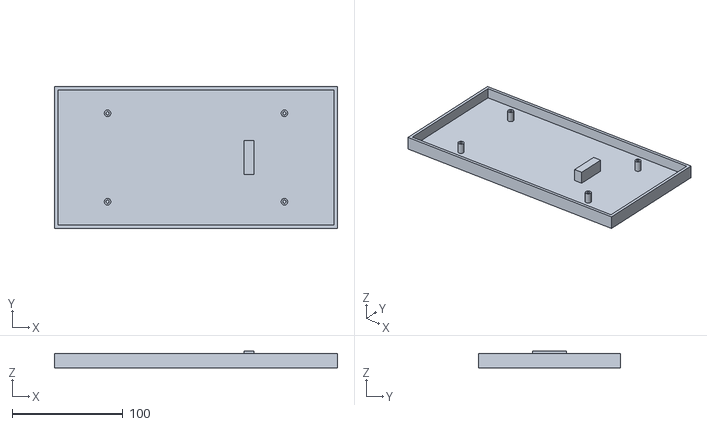
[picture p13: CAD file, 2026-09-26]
enclosure/blender_import/panel_dummy.stl
256.0 x 128.0 x 15.3

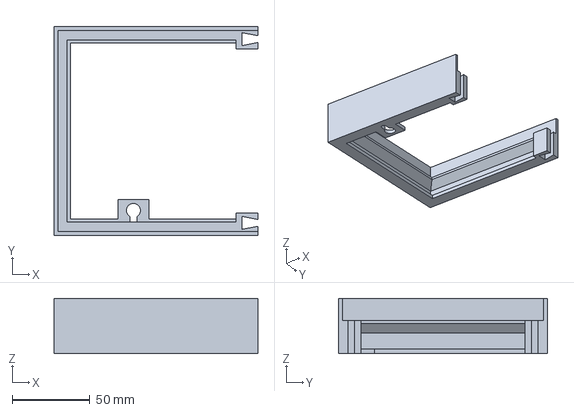
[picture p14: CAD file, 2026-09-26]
enclosure/step/frame_left.step
131.0 x 134.0 x 35.5 mm

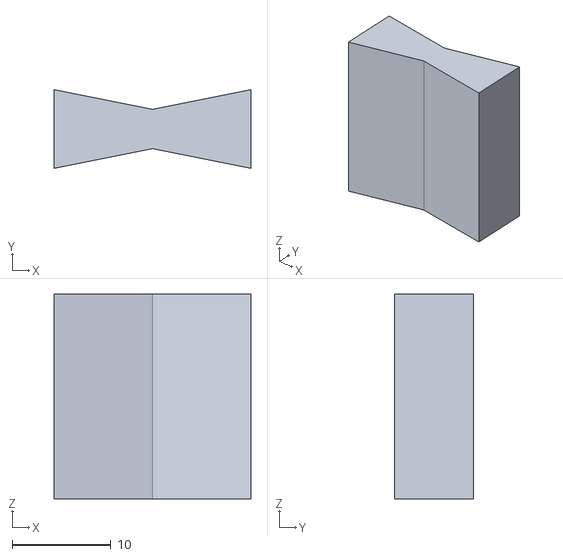
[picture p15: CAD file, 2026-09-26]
enclosure/blender_import/bowtie_key_1.stl
20.0 x 8.00 x 20.8

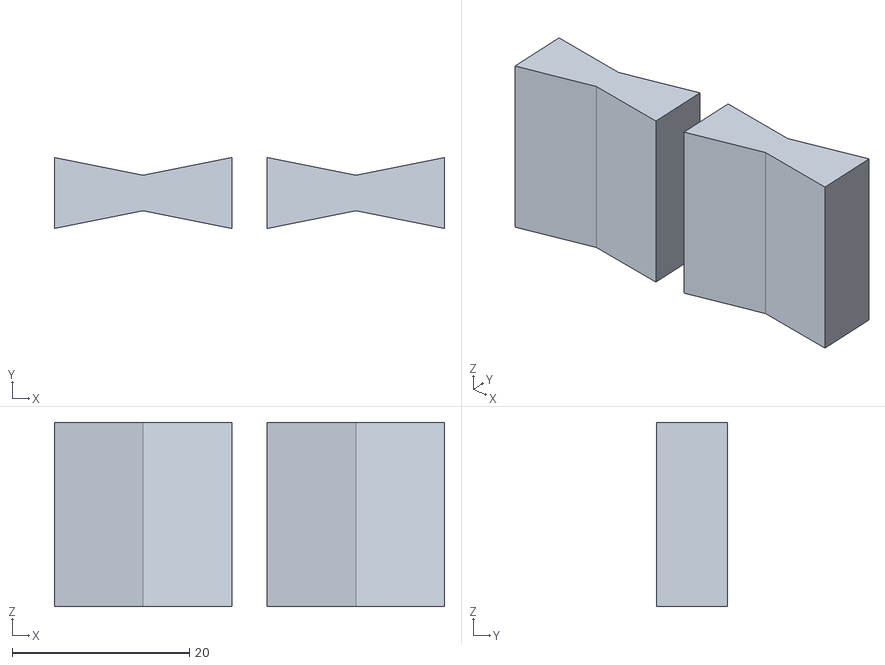
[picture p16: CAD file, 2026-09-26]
enclosure/step/bowtie_keys_cq.stl
44.0 x 8.00 x 20.8

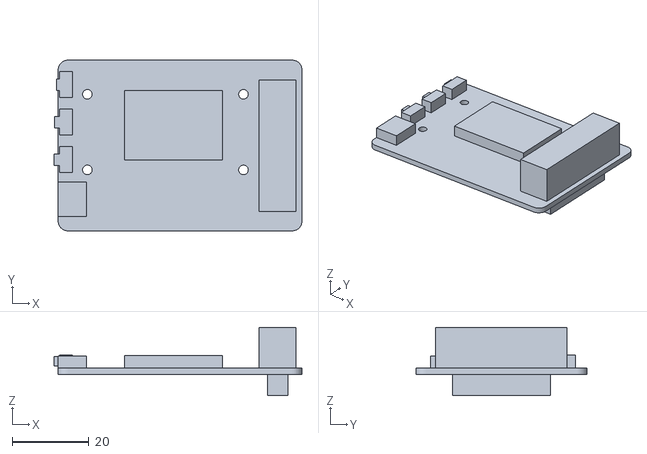
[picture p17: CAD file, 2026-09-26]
enclosure/blender_import/portal_dummy.stl
64.6 x 44.4 x 17.8

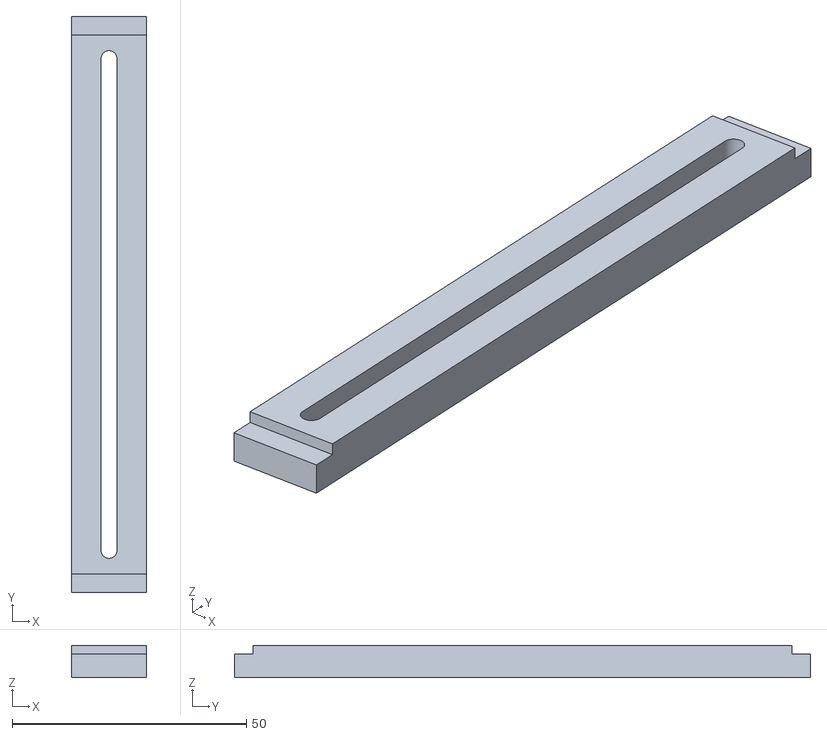
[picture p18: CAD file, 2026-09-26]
enclosure/step/strap_cq.stl
16.0 x 123.0 x 6.90

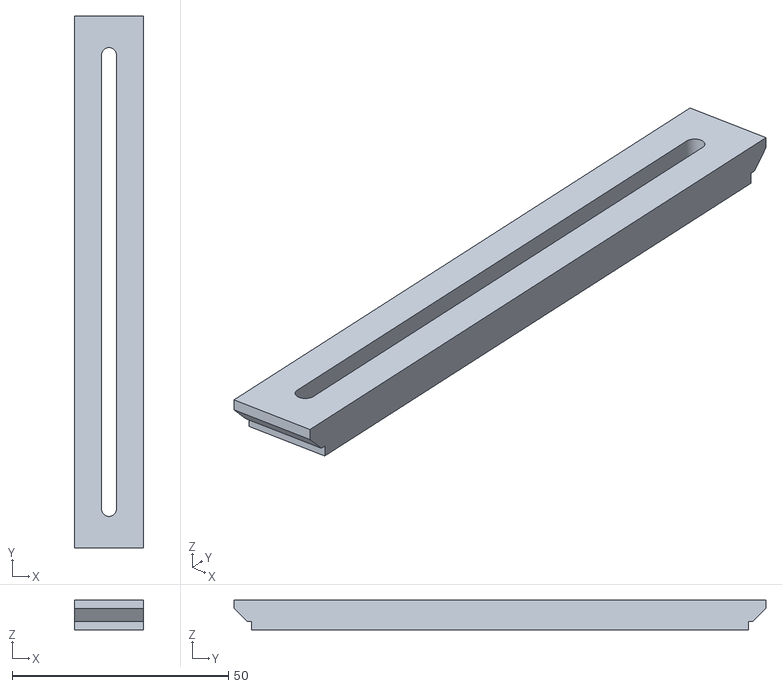
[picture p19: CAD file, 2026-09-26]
enclosure/blender_import/strap_2.stl
16.0 x 123.0 x 6.90

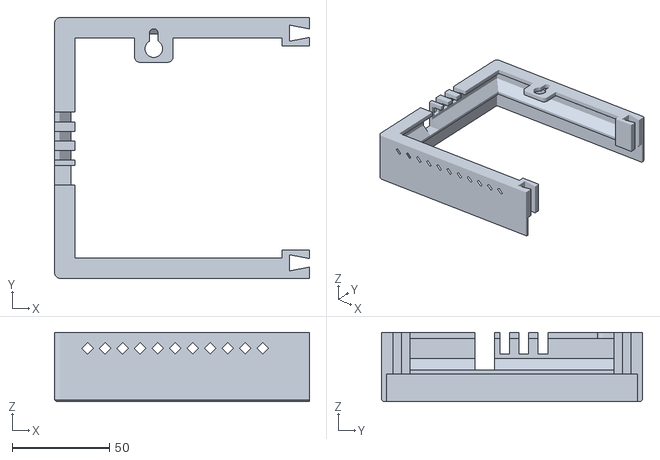
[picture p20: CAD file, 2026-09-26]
enclosure/blender_import/frame_left.stl
131.0 x 134.0 x 35.5

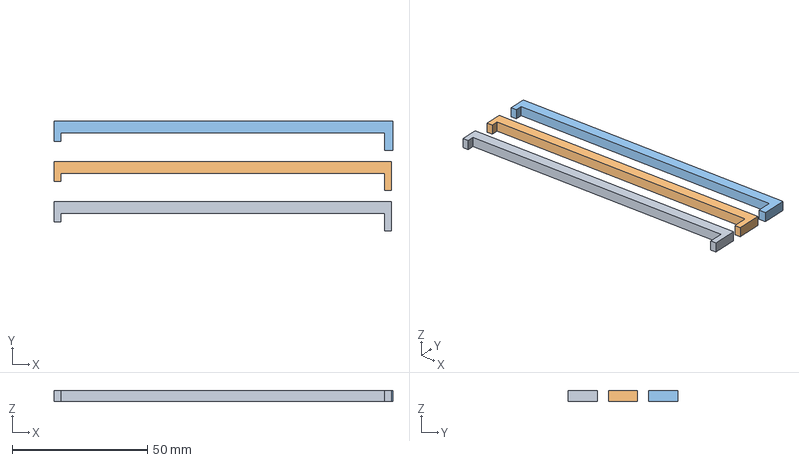
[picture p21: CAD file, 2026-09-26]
enclosure/step/button_rods.step
125.5 x 40.7 x 4.00 mm

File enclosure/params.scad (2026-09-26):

// =====================================================================
//  TailWatch S3 enclosure -- shared, adjustable parameters
//  (included by every part file; edit values HERE, then run tools/build.sh)
// =====================================================================
//
//  COORDINATE SYSTEM ("back view") -- used by every part and parameter:
//    Stand BEHIND the panel, looking at its connectors.
//      +X = to your right, +Y = up, +Z = toward you (toward the wall).
//      z = 0 is the LED face.  (x,y) = (0,0) is the panel's lower-LEFT
//      corner AS SEEN FROM THE BACK (= lower-RIGHT corner seen from the front).
//    Measure every panel-specific position below this way.
//
//  Tags used in comments:
//    [VERIFIED]    taken from a published source (see README "Sources")
//    [MEASURE]     depends on your specific panel/board -- check with calipers
//    [PLACEHOLDER] a guess so the model renders; you MUST set it for your panel
//    [TUNE]        printer / fit tolerance, adjust to taste
// =====================================================================

/* ---------- Print volume (every part is checked against this) ---------- */
bed = [200, 200, 250];            // X, Y, Z build volume in mm (the actual printer;
                                  //   keep tools/build.sh BED in sync)

/* ---------- LED panel ---------- */
panel_w   = 256;                  // [VERIFIED] 128 px * 2.0 mm pitch
panel_h   = 128;                  // [VERIFIED]  64 px * 2.0 mm pitch
panel_thk = 13.0;                 // [MEASURE] LED face -> rearmost flat of the plastic
                                  //   back shell (ignore connectors). 13 mm is the value
                                  //   seen on typical P2 256x128 module listings.
panel_clr = 0.5;                  // [TUNE] gap per side between panel edge and frame wall

// Threaded M3 mounting posts on the back of the panel.  Only used for the
// assembly preview and the "is every strap on a hole?" check -- the printed
// parts do NOT depend on these, because the straps are slotted and can sit
// at any X.  Positions vary by manufacturer and even by batch.
panel_holes  = [[48, 24], [48, 104], [208, 24], [208, 104]];   // [PLACEHOLDER]
panel_hole_d = 3.0;               // M3 is the common size on these modules

// Centre of the panel's HUB75 *INPUT* header (the one the MatrixPortal
// plugs into), back-view coordinates.
hub75_in_xy = [176, 64];          // [PLACEHOLDER] measure yours

// Rotation of the MatrixPortal S3 (as seen from the back, component side up)
// about the header.  0 = board's USB/button edge points to -X (your left when
// behind the panel), 90 = points down (-Y), 180 = right (+X), 270 = up (+Y).
// Must be 0, 90, 180 or 270.
portal_rot = 0;                   // [MEASURE] match your board once plugged in

// LED face -> UNDERSIDE of the MatrixPortal PCB once it is fully seated on
// the panel's header.  Depends on the panel's box-header height and shell.
portal_pcb_z = 15.5;              // [MEASURE] most important depth number. The default
                                  //   leaves 2.5 mm between the PCB underside and a 13 mm
                                  //   shell -- room for the M2.5 screw heads (see pod_fix).

/* ---------- Adafruit MatrixPortal S3 (PID 5778) ----------
   All [VERIFIED] values come from Adafruit's own Eagle board file
   (github.com/adafruit/Adafruit-MatrixPortal-S3-PCB) and 3D model
   (github.com/adafruit/Adafruit_CAD_Parts, "5778 Matrix Portal S3").
   Board frame: origin = PCB lower-left corner in the Eagle top view,
   x along the 63.5 mm edge, z = 0 at the PCB underside.               */
mp_pcb      = [63.5, 44.45];      // [VERIFIED] 2.50" x 1.75" outline
mp_pcb_t    = 1.6;                // [VERIFIED] 1.57 mm in the 3D model
mp_corner_r = 2.54;               // [VERIFIED]
mp_holes    = [[7.62, 15.875], [7.62, 35.56], [48.26, 15.875], [48.26, 35.56]]; // [VERIFIED] 2.5 mm plated
mp_hole_d   = 2.5;                // [VERIFIED] -> M2.5 hardware
mp_socket_c = [57.15, 22.225];    // [VERIFIED] centre of 2x10 socket (underside) == 2x8 IDC (top)
mp_socket   = [5.33, 25.4, 5.55]; // [VERIFIED 3D model] socket body x/y size and depth below PCB
mp_idc_lo   = [52.24, 5.02];      // [VERIFIED 3D model] top-side 2x8 IDC shroud footprint
mp_idc_hi   = [61.90, 39.34];
mp_top_max  = 10.64;              // [VERIFIED 3D model] tallest part above PCB top (IDC shroud)
mp_usb_y    = 8.255;              // [VERIFIED] USB-C centre (mouth flush with the x=0 edge)
mp_usb_bz   = 3.17;               // [VERIFIED 3D model] USB-C centre height above PCB underside
// Right-angle buttons on the x=0 edge: [label, centre y, plunger tip x]
mp_buttons_all = [["DN", 18.542, -1.07],   // [VERIFIED] DOWN
                  ["UP", 28.321, -0.94],   // [VERIFIED] UP (hold at boot = USB-writable)
                  ["RST", 38.100, -0.44]]; // [VERIFIED] RESET
mp_btn_bz   = 3.37;               // [VERIFIED 3D model] plunger centre height above PCB underside
include_reset_pusher = true;      // also make a pusher for RESET (README uses UP + RESET)

/* ---------- Printed-part general ---------- */
wall_t      = 2.5;                // frame wall thickness (>= 2 mm)
face_proud  = 1.0;                // frame lip stands this far IN FRONT of the LED face
                                  //   (protects edges; no overlap onto pixels)
frame_corner_r = 3.0;             // outer corner radius of the frame

/* ---------- Panel retention ledge (45-degree wedge behind the panel edge) ---------- */
ledge_w   = 6.0;                  // how far the ledge reaches in behind the panel edge
ledge_tip = 2.0;                  // thickness of the ledge at its inner tip
ledge_gap = 0.2;                  // [TUNE] panel back shell -> ledge front clearance

/* ---------- Rear flange (sits flat on the wall, carries keyholes) ---------- */
flange_w = 8.0;
flange_t = 3.0;
frame_back_z_override = 0;        // 0 = automatic (just behind the MatrixPortal pod)
wall_gap_min = 3.0;               // min air gap between pod roof and the wall

/* ---------- Frame split (two halves joined by printed bowtie keys) ---------- */
seam_x    = panel_w / 2;          // where the frame is split
boss_len  = 28;                   // seam boss length along X
boss_d    = 12;                   // seam boss depth, inward from wall
bt_len    = 20;                   // bowtie key length (across the seam)
bt_waist  = 4.0;                  // bowtie width at the seam
bt_end    = 8.0;                  // bowtie width at its ends
bt_clr    = 0.15;                 // [TUNE] key clearance per side (tight = glue optional)

/* ---------- Wall hanging: keyhole slots in the top flange ---------- */
keyhole_spacing = 160;            // centre-to-centre of the two wall screws
kh_head_d  = 9.0;                 // entry hole (fits a ~8 mm pan/round screw head)
kh_shank_d = 4.5;                 // slot width (#6-#8 / 3.5-4 mm wood screw shank)
kh_slot    = 8.0;                 // slot length (entry-hole centre -> hang position)
kh_boss_w  = 20;                  // flange widened to this around each keyhole

/* ---------- Ventilation (diamond holes in top and bottom walls) ---------- */
vent_d     = 6.0;                 // diamond diagonal (no bridging needed)
vent_pitch = 9.0;

/* ---------- Panel 5 V cable entry (bottom wall, open from the rear) ---------- */
power_notch_x = 200;              // [PLACEHOLDER] put it near your panel's power input
power_notch_w = 9.0;              // fits a 5.5x2.1 DC-plug cable or 2x 18 AWG leads
power_notch_bottom_z = 18.0;      // notch floor, measured from LED face

/* ---------- USB-C cable exit (frame wall facing the board's USB edge) ---------- */
usb_notch_w  = 10.0;
usb_notch_dz = 3.5;               // notch floor sits this far below the USB-C centre

/* ---------- Rear straps (hold the panel in the frame) ---------- */
strap_xs      = [48, 208];        // [PLACEHOLDER] X of each strap = X of a column of
                                  //   panel M3 posts. One strap per frame half minimum.
strap_w       = 16;
strap_t       = 5.0;
strap_slot_w  = 3.4;              // M3 clearance
strap_overlap = 3.0;              // strap end reaches this far over the ledge wedge
strap_clr     = 0.2;              // [TUNE] strap end <-> ledge wedge clearance
strap_preload = 0.3;              // rib is this much short so screws clamp the ledge
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

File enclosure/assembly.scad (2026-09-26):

// TailWatch S3 enclosure -- assembly preview (NOT a printable part).
// Shows every printed part in place on dummy panel / MatrixPortal models.
//   explode = 0      assembled; try 40 for an exploded view
//   upright = true   rotate so the display stands as it hangs on the wall
//                    (world +Z = up, the LED face looks toward world +Y)
include <tailwatch_lib.scad>
explode = 0;
upright = false;
run_checks();
if (upright) rotate([90, 0, 0]) assembly(explode);
else assembly(explode);

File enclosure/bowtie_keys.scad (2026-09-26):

// TailWatch S3 enclosure -- bowtie_keys
// Two bowtie keys that join the frame halves. Standing as exported.
// Exported in print orientation; no supports needed.
include <tailwatch_lib.scad>
run_checks();
keys_print();

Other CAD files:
enclosure/step/frame_right_cq.stl
enclosure/blender_import/bowtie_key_2.stl
enclosure/step/strap.step
enclosure/step/frame_right.step
enclosure/blender_import/frame_right.stl
enclosure/step/portal_pod.step
enclosure/blender_import/strap_1.stl
enclosure/button_rods.scad
enclosure/blender_import/bowtie_key_1_positioned.scad
enclosure/blender_import/bowtie_key_2_positioned.scad
enclosure/blender_import/button_rods.stl
enclosure/blender_import/button_rods_positioned.scad
enclosure/blender_import/frame_left_positioned.scad
enclosure/blender_import/frame_right_positioned.scad
enclosure/blender_import/panel_dummy_positioned.scad
enclosure/blender_import/portal_dummy_positioned.scad
enclosure/blender_import/portal_pod_positioned.scad
enclosure/blender_import/strap_1_positioned.scad
enclosure/blender_import/strap_2_positioned.scad
enclosure/frame_left.scad
enclosure/frame_right.scad
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

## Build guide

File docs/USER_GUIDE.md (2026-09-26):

# TailWatch User Guide

Welcome to TailWatch — your window into the aircraft flying nearby. This guide will help you set up and use your wall-mounted display.

---

## What It Does

TailWatch is a wall display that shows one airplane flying near your location in real time. Each time you look, you see that plane's flight number, airline, route, current altitude, and speed — plus the city it's departing from or arriving at. The display updates every 15 seconds or so, and if a different, closer aircraft comes into view, the display smoothly switches to show that instead. If the skies are empty, it tells you `NO TRAFFIC`. It runs on its own after setup — no app, no subscription, no constant internet required (though it does need Wi-Fi for your home network to fetch live data).

---

## First-Time Setup

### Power On

Plug the USB cable into your home power adapter and connect it to the device. Within a few seconds, you'll see something happen on the screen.

### If Wi-Fi Works

If TailWatch can reach your home Wi-Fi, it will join automatically and display a flight card.

### If Wi-Fi Doesn't Connect

If TailWatch hasn't been set up before, or if it can't find your Wi-Fi, the screen will show:

```
WIFI SETUP
TailWatch-XXXX
pw xxxxxxxx
192.168.4.1
```

This is the device's own temporary Wi-Fi network (a "hotspot"), plus its password and web address. Here's how to use it:

1. On your phone, go to **Settings** > **Wi-Fi** and look for the network called `TailWatch-XXXX` (where `XXXX` are four random characters shown on the panel). Join it using the password shown on the screen.

2. Open a web browser and navigate to `192.168.4.1`. You'll see a settings page with a Wi-Fi form at the top.

3. Under "Network name (SSID)," enter your home Wi-Fi network name. Under "Password," enter your Wi-Fi password. If your network has no password, check the "Open network" box instead.

4. Tap **Save Wi-Fi & restart** at the bottom. TailWatch will restart and join your home network.

5. Go back to your phone's Wi-Fi settings and reconnect to your normal home network. TailWatch is now online.

If you get the network name or password wrong, or if your Wi-Fi is unreachable, TailWatch will come back up as the `TailWatch-XXXX` hotspot so you can try again. There's always a way to recover — you'll never be stuck.

---

## Setting Your Location

Once TailWatch is on your home network, you can open its settings page to tell it where you are.

1. On your phone or computer, find TailWatch's address: check your router's device list for its IP address (it looks like `192.168.x.x`), or check the serial output if you have it plugged into a computer. Visit that address in a web browser.

2. You'll see the settings page. Look for the **Latitude** and **Longitude** fields near the top, and enter your home's coordinates. (You can find these by searching your address on Google Maps — right-click and copy the numbers.)

3. Below that is a field called **Box (miles each way)**. This is your "search radius" — how far out to look for aircraft. The default is 10 miles in each direction, which means a 20-mile-wide box centered on your location. Adjust this to taste:
   - **5–10 miles** if you live near a busy airport — you'll see planes constantly.
   - **15–20 miles** if you live farther out — more variety, but longer waits between aircraft.
   - **25–50 miles** if you want to see even distant traffic.

4. Tap **Save** to store your settings.

After this, TailWatch will show aircraft that are within your box, closest to your location first.

---

## Customizing the Display

The settings page has several ways to personalize your experience.

### Brightness

You can set how bright the display is during the day, at night, and at maximum. Use the three sliders under **Brightness**:
- **Day**: How bright during daylight hours (try 0.60–0.80).
- **Night**: How bright after dark (try 0.15–0.30 so it doesn't light up your room).
- **Max cap**: The absolute ceiling — even in day mode, it won't exceed this.

### Night Mode

Under **Night mode**, choose one of three options:
- **Off**: Display stays at day brightness all the time.
- **Fixed hours**: Switch to night brightness at a specific time (e.g., 9:00 PM to 6:30 AM). Enter the times under **Night start** and **Night end**.
- **After local sunset**: Uses your location and the time of year to switch automatically after sunset each day.

Night mode only dims the display. To turn it completely off on a schedule, use **Sleep** instead.

### Sleep (Display Off)

If you want the display to go completely dark during certain hours (e.g., so it doesn't run all night), use the **Sleep** section:
- Check **Enable sleep**.
- Enter your sleep start and end times (e.g., 11:00 PM to 6:30 AM).

During sleep hours, the screen will be completely blank. Aircraft polling pauses too, saving power.

### Filters

Under **Filters**, you can hide certain types of aircraft:
- **Hide helicopters**: Removes medical, police, and private helicopters.
- **Hide general aviation**: Removes small private planes (single-engine Cessnas, etc.).
- **Hide military**: Removes military and government aircraft.

These are optional. If you uncheck them, you'll see all traffic.

### Time Zone

Under **Local time**, select your time zone from the dropdown. This is used for sleep and night-mode schedules. If you're in the US, also check **Apply US daylight saving** so the device adjusts automatically on the second Sunday in March and first Sunday in November. (Uncheck this if you live in Arizona, Hawaii, or outside the US.)

---

## Understanding the Screen

Most of the time, you'll see a flight card with the plane's details. But sometimes you'll see other messages — here's what they mean.

### NO TRAFFIC

The screen shows `NO TRAFFIC` when there are no aircraft in your search box at that moment, or they're all filtered out. This is completely normal. Come back in a minute or two and a new plane will likely appear.

### NO LINK

The screen shows `NO LINK` if TailWatch can't reach the aircraft data source. This usually happens temporarily — maybe your internet is down, or the data service is busy. TailWatch will keep retrying. The display is fine, and your settings are still saved. Wait a minute and check again.

---

## Moving or Changing Your Wi-Fi Network

If you move to a new home or change your Wi-Fi network name or password, you don't need to do anything special.

The next time TailWatch tries to connect and fails, it will automatically show the `WIFI SETUP` screen with the temporary hotspot name and password (just like the first-time setup). Simply join that hotspot, open `192.168.4.1`, and enter your new network details. No factory reset needed — everything else stays the same.

---

## The Secret Animation

Here's a fun easter egg: if you hold down the **DOWN** button on the device for 5 seconds, a colorful Nyan Cat animation will play across the screen for up to 90 seconds. To stop it early, just press either the **UP** or **DOWN** button again. The display will return to showing aircraft.

---

## Troubleshooting

### The screen is dark or blank

1. Check your **Sleep** settings. If sleep is enabled and the current time falls within the sleep window, the screen will be off. Either disable sleep or adjust the times.
2. Check your **Night mode** and brightness settings. If night mode is on and the night brightness is set very low (below 0.10), the display might look almost black. Try increasing the night brightness slider.
3. Make sure the device is powered and plugged in.

### I can't find the `TailWatch-XXXX` setup network

1. Make sure the device is powered on.
2. Check your phone's Wi-Fi list again — the network name appears there only when the device is in setup mode (i.e., when it can't join your home Wi-Fi).
3. Look at the device's screen. It should show `WIFI SETUP` and the network name. If it shows a flight card instead, the device is already connected to your home network, and you can visit the settings page instead.

### I forgot which Wi-Fi my device is on

1. Look at your router's device list (usually found in the router's admin page, often at `192.168.1.1`). Find "TailWatch" or "MatrixPortal" in the list — it will show the IP address.
2. Alternatively, plug the device into a USB cable connected to a computer and check the serial console output. The IP address is printed there.

### The settings page won't load

1. Make sure your phone is on the same Wi-Fi network as TailWatch.
2. Double-check the IP address. Check your router's device list for the address (it looks like `192.168.x.x`) -- it can change if your router reassigns it.
3. Wait 10–15 seconds and try again. TailWatch may be busy polling for aircraft data.

### Aircraft information is missing or incomplete

If the display shows partial data or says `NO LINK`, TailWatch is having trouble reaching the OpenSky aircraft data service. This is usually temporary. Wait a minute and the data should come back.

### I want to change my location without setting up Wi-Fi again

Simply visit the settings page on your home network and update the **Latitude**, **Longitude**, and **Box (miles each way)** fields. You don't need to rejoin Wi-Fi or restart.

---

## Tips for Best Results

- **Place it where you can see it**: The display is bright in daylight but dim at night. Mount it where it catches your eye during the day but won't be distracting at night.
- **Adjust your search radius**: A smaller box (5–10 miles) shows fewer planes but faster updates. A larger box shows more variety but longer waits between aircraft.
- **Experiment with filters**: If you're mostly interested in commercial airliners, hide helicopters and general aviation. If you want to see everything, disable the filters.
- **Check Wi-Fi signal**: Make sure your device has a good Wi-Fi signal. If it drops connection often, it may not update reliably.

Enjoy watching the skies!

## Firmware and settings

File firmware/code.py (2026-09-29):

import time
import json
import os
import gc
import board
import microcontroller
import displayio
import framebufferio
import rgbmatrix
import wifi
import socketpool
import rtc
import adafruit_ntp
from adafruit_httpserver import Server, Request, Response, Status, GET, POST, Redirect

from prefs import load, apply_form, public
from urldecode import unquote_plus
from schedule import sleeping, brightness, set_clock_synced, clock_synced, clock_trusted
from dim import Dimmer, min_visible
import wifisettings
import httpclient
import reqguard
import net
import filters
import enrich
from hero import Hero, candidates as hero_candidates
from captiveportal import CaptiveDNS
from linkwatch import LinkWatch, UP as LINK_UP

displayio.release_displays()

# rgbmatrix color depth. DESIGN.md caps MVP at 3-4; 4 gives 15 lit levels per
# channel (3 gives 7), which the color-scaling dimmer in lib/dim.py needs for
# the night slider to stay visibly distinct from gray labels. Drop to 3 if the
# panel flickers or the HTTP server gets sluggish on real hardware.
BIT_DEPTH = 4

matrix = rgbmatrix.RGBMatrix(
    width=128,
    height=64,
    bit_depth=BIT_DEPTH,
    rgb_pins=[
        board.MTX_R1, board.MTX_G1, board.MTX_B1,
        board.MTX_R2, board.MTX_G2, board.MTX_B2,
    ],
    addr_pins=[
        board.MTX_ADDRA, board.MTX_ADDRB, board.MTX_ADDRC,
        board.MTX_ADDRD, board.MTX_ADDRE,
    ],
    clock_pin=board.MTX_CLK,
    latch_pin=board.MTX_LAT,
    output_enable_pin=board.MTX_OE,
    tile=1,
    serpentine=False,
    doublebuffer=True,
)
display = framebufferio.FramebufferDisplay(matrix, auto_refresh=True)

# Placeholder content until lib/card.py exists: a 1 px white frame plus
# white / gray / amber bars, all drawn through one palette so the dimmer can
# rescale it. Deliberately sparse -- a full-white panel is ~15 W.
PLACEHOLDER_COLORS = (
    0x000000,  # 0 background
    0xFFFFFF,  # 1 white (frame + top bar): card text
    0x999999,  # 2 gray (middle bar): card labels
    0xFF7900,  # 3 amber (bottom bar): accent
)


def _make_placeholder():
    w, h = display.width, display.height
    bmp = displayio.Bitmap(w, h, len(PLACEHOLDER_COLORS))
    for x in range(w):
        bmp[x, 0] = 1
        bmp[x, h - 1] = 1
    for y in range(h):
        bmp[0, y] = 1
        bmp[w - 1, y] = 1
    for idx, y0 in ((1, 14), (2, 29), (3, 44)):
        for y in range(y0, y0 + 6):
            for x in range(8, w - 8):
                bmp[x, y] = idx
    pal = displayio.Palette(len(PLACEHOLDER_COLORS))
    group = displayio.Group()
    group.append(displayio.TileGrid(bmp, pixel_shader=pal))
    return group, pal


placeholder_group, placeholder_pal = _make_placeholder()
display.root_group = placeholder_group
dimmer = Dimmer(display, placeholder_group, displayio.Group(), floor=min_visible(BIT_DEPTH))
dimmer.add_palette(placeholder_pal, PLACEHOLDER_COLORS)

prefs = load()
dimmer.apply(brightness(prefs))
print("brightness", dimmer.level)

# ---- Network bring-up: join as a station, else fall back to a setup AP ----
# DESIGN.md sec. 7: "CIRCUITPY_WIFI_SSID empty or join fails for 20 s".
JOIN_ATTEMPTS = 2
JOIN_TIMEOUT_S = 10          # 2 x 10 s ~= the 20 s budget
AP_IDLE_RETRY_S = 600        # AP + configured SSID: reboot to retry after 10 min without UI traffic
AP_TEXT_COLOR = 0x707070     # fixed mid-gray setup text (dimmer not used in AP mode)
RESET_DELAY_S = 3.0          # let the POST /api/wifi response flush before resetting
NTP_RETRY_S = 300            # station mode, clock not yet synced
NTP_RESYNC_S = 86400         # station mode, daily re-sync for RTC drift
HTTP_FAIL_LIMIT = 5          # consecutive server.poll() exceptions -> restart the server
HTTP_RETRY_S = 30            # server failed to start: retry this often
PW_ALPHABET = "abcdefghijkmnpqrstuvwxyz23456789"  # 32 chars, no l/o/0/1


def join_station():
    """(joined, configured_ssid). Never prints the password."""
    ssid = str(os.getenv("CIRCUITPY_WIFI_SSID") or "")
    if not ssid:
        return False, ""
    if wifi.radio.ipv4_address is not None:
        return True, ssid  # CircuitPython already auto-joined from settings.toml
    pw = str(os.getenv("CIRCUITPY_WIFI_PASSWORD") or "")
    for i in range(JOIN_ATTEMPTS):
        try:
            wifi.radio.connect(ssid, pw, timeout=JOIN_TIMEOUT_S)
            return True, ssid
        except Exception as e:  # ConnectionError (no AP / auth failed), ValueError (bad pw length)
            print("wifi join %d/%d failed: %s" % (i + 1, JOIN_ATTEMPTS, e))
    return False, ssid


def scan_networks(limit=12):
    """([{ssid, rssi}] strongest first, quietest of channels 1/6/11). Station must be up."""
    best = {}
    load_by_ch = {1: 0, 6: 0, 11: 0}
    try:
        for n in wifi.radio.start_scanning_networks():
            if n.channel in load_by_ch:
                load_by_ch[n.channel] += 1
            if n.ssid and (n.ssid not in best or n.rssi > best[n.ssid]):
                best[n.ssid] = n.rssi
    except Exception as e:
        print("scan", e)
    try:
        wifi.radio.stop_scanning_networks()
    except Exception:
        pass
    nets = sorted(best.items(), key=lambda kv: -kv[1])[:limit]
    chan = min((1, 6, 11), key=lambda c: load_by_ch[c])
    return [{"ssid": s, "rssi": r} for s, r in nets], chan


def start_setup_ap():
    """Start WPA2 AP TailWatch-XXXX with a fresh random password. Returns
    (ap_ssid, ap_password, host_ip, networks)."""
    nets, chan = scan_networks()  # scan first: ESP32-S3 can't scan once AP-only
    try:
        wifi.radio.stop_station()  # stop STA retries so the radio stays on the AP channel
    except Exception as e:
        print("stop_station", e)
    mac = wifi.radio.mac_address
    ap_ssid = "TailWatch-%02X%02X" % (mac[-2], mac[-1])
    ap_pw = "".join(PW_ALPHABET[b & 31] for b in os.urandom(8))
    wifi.radio.start_ap(
        ap_ssid,
        ap_pw,
        channel=chan,
        authmode=[wifi.AuthMode.WPA2, wifi.AuthMode.PSK],
        max_connections=2,
    )
    host_ip = str(wifi.radio.ipv4_address_ap or "192.168.4.1")
    return ap_ssid, ap_pw, host_ip, nets


def show_setup_screen(lines):
    from setupscreen import build  # lazy: only AP mode pays for adafruit_display_text
    display.root_group = build(lines, AP_TEXT_COLOR)
    display.brightness = 1.0  # never blank the setup screen (dimmer is bypassed in AP mode)


wifisettings.recover()  # finish an interrupted settings.toml swap before reading it
sta_ok, cfg_ssid = join_station()
ap_mode = not sta_ok
ap_ssid = ""
networks = []
if ap_mode:
    try:
        ap_ssid, ap_pw, host, networks = start_setup_ap()
    except Exception as e:
        print("AP start failed", e, "- rebooting in 60 s")
        time.sleep(60)
        microcontroller.reset()
    print("SETUP: join Wi-Fi %s password %s, open http://%s/" % (ap_ssid, ap_pw, host))
    try:
        show_setup_screen(("WIFI SETUP", ap_ssid, "pw " + ap_pw, host))
    except Exception as e:  # missing adafruit_display_text etc.: serial still has it
        print("setup screen", e)
else:
    host = str(wifi.radio.ipv4_address)

# Station mode only: re-join after a Wi-Fi drop and move the web UI to the
# new address (lib/linkwatch.py). AP mode has its own idle-reboot retry.
link = None
if not ap_mode:
    link = LinkWatch(
        wifi.radio, cfg_ssid,
        lambda: str(os.getenv("CIRCUITPY_WIFI_PASSWORD") or ""),
        host, connect_timeout=JOIN_TIMEOUT_S,
    )

pool = socketpool.SocketPool(wifi.radio)
_ntp = None

# AP mode only (issue #21): answer every DNS query with our own IP so a
# joining phone/laptop's captive-portal detection probes resolve to us
# instead of timing out (there's no internet to resolve anything for real),
# which is what makes the OS auto-pop its sign-in browser -- see the
# CAPTIVE_CHECK_PATHS routes below for the HTTP side of that handshake.
captive_dns = None
if ap_mode:
    try:
        captive_dns = CaptiveDNS(pool, host)
    except Exception as e:
        print("captiveportal: DNS start failed", e)  # setup still reachable at the AP's own IP


def sync_clock():
    """NTP -> RTC (UTC). Marks the clock trusted for lib/schedule.py on success."""
    global _ntp
    try:
        if _ntp is None:
            _ntp = adafruit_ntp.NTP(pool, tz_offset=0, socket_timeout=5)
        rtc.RTC().datetime = _ntp.datetime
        set_clock_synced(True)
        print("ntp ok", time.time())
        return True
    except Exception as e:
        print("ntp failed", e)
        return False


if not ap_mode:  # no uplink in AP mode: skip the timeout
    sync_clock()
if not clock_trusted():
    print("clock not set: sleep/night schedule paused, day brightness")

reset_at = None                # monotonic deadline for microcontroller.reset()
last_api = time.monotonic()    # last /api/* request (AP idle-retry timer)


def _touch():
    global last_api
    last_api = time.monotonic()


def _json(request, obj, code=200, reason="OK"):
    return Response(request, json.dumps(obj), content_type="application/json",
                    status=Status(code, reason))


def _guard(request, write):
    """403 Response if the request isn't same-origin for this device, else None.
    Reads the global `host`, so it follows LinkWatch IP changes and AP mode."""
    h = request.headers  # adafruit_httpserver Headers: case-insensitive .get
    why = reqguard.check(h.get("Host"), h.get("Origin"), h.get("Referer"), host, write)
    if why is None:
        return None
    print("api 403:", why)
    return _json(request, {"error": "forbidden: " + why}, 403, "Forbidden")


def _read_form(request, include_query=True):
    """(form dict, is_json); form is None for an unparseable JSON body."""
    form = {}
    is_json = request.headers.get("Content-Type", "").lower().startswith("application/json")
    try:
        if is_json:
            form = json.loads(request.body)
        else:
            # adafruit_httpserver splits fields but does NOT percent-decode,
            # and .get()/.items() HTML-escape values (safe=True) -- so read raw
            # values via fd[k] and decode them ourselves.
            if include_query:
                qp = request.query_params
                for k in qp:
                    form[unquote_plus(k)] = unquote_plus(qp[k])
            fd = request.form_data
            if fd is not None:
                urlenc = fd.content_type == "application/x-www-form-urlencoded"
                for k in fd:
                    v = fd[k]  # raw first value
                    if isinstance(v, bytes):
                        v = v.decode()
                    if urlenc:
                        k, v = unquote_plus(k), unquote_plus(v)
                    form[k] = v
    except Exception as e:
        print("parse", e)
        if is_json:
            form = None
    if is_json and not isinstance(form, dict):
        form = None
    return form, is_json


def get_prefs(request: Request):
    bad = _guard(request, False)
    if bad:
        return bad
    _touch()
    return _json(request, public(load()))


def post_prefs(request: Request):
    global prefs
    bad = _guard(request, True)
    if bad:
        return bad
    _touch()
    form, is_json = _read_form(request)
    if form is None:
        return _json(request, {"error": "invalid JSON body"}, 400, "Bad Request")
    try:
        prefs = apply_form(load(), form, partial=is_json)
    except OSError as e:
        print("prefs save failed", e)
        return Response(
            request,
            json.dumps({"error": "prefs storage read-only (booted with UP held?)"}),
            content_type="application/json",
            status=Status(503, "Service Unavailable"),
        )
    if not ap_mode and dimmer.apply(brightness(prefs)):
        print("brightness", dimmer.level)
    return _json(request, public(prefs))


def get_status(request: Request):
    bad = _guard(request, False)
    if bad:
        return bad
    _touch()
    return _json(request, {
        "mode": "ap" if ap_mode else "sta",
        "ip": host,
        "ssid": cfg_ssid,          # configured station SSID; the password is never returned
        "ap_ssid": ap_ssid,
        "networks": networks,      # scanned before the AP started ([] in station mode)
        "clock_synced": clock_synced(),
        "clock_trusted": clock_trusted(),
        "rebooting": reset_at is not None,
        "wifi_drops": link.drops if link is not None else 0,  # station outages since boot
    })


def post_wifi(request: Request):
    """Allow-listed {ssid, password, open} -> /settings.toml, then hard reset."""
    global reset_at
    bad = _guard(request, True)
    if bad:
        return bad
    _touch()
    form, _ = _read_form(request, include_query=False)  # keep passwords out of URLs/logs
    if form is None:
        return _json(request, {"error": "invalid JSON body"}, 400, "Bad Request")
    try:
        ssid, pw = wifisettings.from_form(form)
        wifisettings.save(ssid, pw)
    except ValueError as e:
        return _json(request, {"error": str(e)}, 400, "Bad Request")
    except OSError as e:
        print("wifi save failed", e)
        return _json(request, {"error": "settings.toml read-only (booted with UP held?)"},
                     503, "Service Unavailable")
    print("wifi saved for", ssid, "- hard reset in", RESET_DELAY_S, "s")
    reset_at = time.monotonic() + RESET_DELAY_S
    return _json(request, {"ok": True, "ssid": ssid, "rebooting": True})


# AP mode only (issue #21): known captive-portal detection probe paths.
# Each OS expects a specific exact response (Android: 204 + empty body,
# Apple: 200 + one exact HTML string, Windows: specific plain-text bodies)
# and treats *anything else* as "there's a portal" -- so redirecting these
# to the setup page, rather than trying to impersonate the expected body, is
# what makes the OS auto-launch its captive sign-in browser here instead of
# just flagging "limited connectivity" and leaving the user to find the IP.
CAPTIVE_CHECK_PATHS = (
    "/generate_204", "/gen_204",                            # Android
    "/hotspot-detect.html", "/library/test/success.html",   # Apple
    "/connecttest.txt", "/ncsi.txt", "/redirect",           # Windows
    "/success.txt",                                          # Firefox
)


def captive_redirect(request: Request):
    return Redirect(request, "http://%s/" % host)


def start_http():
    """Start the web UI on port 80. Returns the Server, or None on any failure.

    Port 80 is already taken if CircuitPython's Web Workflow is enabled
    (CIRCUITPY_WEB_API_PASSWORD in settings.toml) -- keep it off.
    """
    try:
        srv = Server(pool, "/www", debug=True)
        srv.route("/api/prefs", GET)(get_prefs)
        srv.route("/api/prefs", POST)(post_prefs)
        srv.route("/api/status", GET)(get_status)
        srv.route("/api/wifi", POST)(post_wifi)
        if ap_mode:
            for p in CAPTIVE_CHECK_PATHS:
                srv.route(p, GET)(captive_redirect)
        srv.start(host, 80)  # station IP, or 192.168.4.1 in AP mode
    except Exception as e:
        print("http start failed", e)
        return None
    print("ui http://%s/" % host)
    return srv


server = start_http()
http_fails = 0                  # consecutive server.poll() exceptions
last_http_try = time.monotonic()


def restart_http(why):
    """Stop the web UI server (if any) and start a fresh one on `host`."""
    global server, http_fails, last_http_try
    print("http: restarting on %s (%s)" % (host, why))
    if server is not None:
        try:
            server.stop()
        except Exception as e:  # socket already dead with the old link
            print("http stop", e)
    server = None
    gc.collect()
    server = start_http()
    http_fails = 0
    last_http_try = time.monotonic()


hero = Hero(poll_s=15)  # DESIGN.md sec. 8: on-device hero selection (issue #2)


def poll_card():
    """lib/net.py -> lib/filters.py -> lib/hero.py, assembled into a card dict.

    Raises whatever lib/net.py's OpenSky fetch raises (httpclient.HTTPStatusError
    on a non-200, OSError / RuntimeError / TimeoutError / ValueError otherwise) --
    the caller (the main loop, below) is what turns that into "keep the last
    good card" per DESIGN.md sec. 8; this function never swallows a failure or
    guesses at that policy itself. Only call it while link.state == LINK_UP
    (the main loop already gates poll_card() on that).

    route/type/city/phase are not populated: nothing on-device (no cloud tier,
    issue #2) currently supplies flight-route, aircraft-type, or airport/phase
    data for a raw ADS-B state vector -- lib/hero.py's own docstring only
    promises position/altitude/speed/track from OpenSky. Left as "" rather
    than invented, same shape DESIGN.md sec. 8's card documents either way.
    """
    resp = net.poll(pool, prefs)
    cands = filters.apply(hero_candidates(resp, prefs["lat"], prefs["lon"]), prefs)
    c, why = hero.select(cands, time.monotonic())
    print("hero", why, c["hex"] if c else None)
    if c is None:
        return {"flight": None, "airline": "", "logo": None, "route": "", "type": "",
                "city": "", "phase": "", "alt": None, "spd": None, "track": None,
                "hex": None, "age_s": None}
    enr = enrich.lookup(c["cs"])
    return {
        "flight": c["cs"] or c["hex"],
        "airline": enr[0] if enr else "",
        "logo": enr[1] if enr else None,
        "route": "",
        "type": "",
        "city": "",
        "phase": "",
        "alt": c["alt"],
        "spd": c["spd"],
        "track": c["trk"],
        "hex": c["hex"],
        "age_s": c["age"],
    }


last_poll = 0
poll_backoff_until = 0   # monotonic deadline; set past a 429's Retry-After
last_card = None         # last successfully assembled card (kept across failed polls)
last_bright = 0
last_ntp_try = time.monotonic()
while True:
    # Skip while the station link is down: nothing can reach the UI, and a
    # dead listening socket would otherwise log an error every pass.
    if server is not None and (link is None or link.state == LINK_UP):
        try:
            server.poll()
            http_fails = 0
        except Exception as e:
            http_fails += 1
            print("http", e)
            if http_fails >= HTTP_FAIL_LIMIT:
                restart_http("%d consecutive poll errors" % http_fails)

    now = time.monotonic()
    if reset_at is not None and now >= reset_at:
        microcontroller.reset()  # hard reset: boot.py + settings.toml re-read, fresh radio

    if server is None and now - last_http_try >= HTTP_RETRY_S and (
            link is None or link.state == LINK_UP):
        restart_http("not running")

    if link is not None and reset_at is None:
        ev = link.tick()  # may block up to JOIN_TIMEOUT_S while reconnecting
        if ev is not None:
            if ev[0] == "down":
                httpclient.reset()  # pooled outbound sockets died with the link
            elif ev[0] == "up":
                host = ev[2]
                httpclient.reset()
                restart_http("wifi up" if ev[1] == ev[2] else "ip %s -> %s" % (ev[1], ev[2]))
                if not clock_synced():
                    last_ntp_try = now - NTP_RETRY_S  # retry NTP now, not in up to 5 min
            elif ev[0] == "reset":
                # Boots, fails the ~20 s join, and comes up as the setup AP,
                # which itself reboots to retry after AP_IDLE_RETRY_S idle.
                microcontroller.reset()
        now = time.monotonic()  # tick() may have blocked
    online = link is not None and link.state == LINK_UP

    if ap_mode:
        if captive_dns is not None:
            captive_dns.poll()
        # Configured network down (router rebooting, outage)? Retry it by
        # rebooting once nobody has used the setup UI for AP_IDLE_RETRY_S.
        # With no SSID configured, stay in setup mode indefinitely.
        if cfg_ssid and reset_at is None and now - last_api >= AP_IDLE_RETRY_S:
            print("setup AP idle; rebooting to retry", cfg_ssid)
            microcontroller.reset()
        time.sleep(0.05)
        continue

    prefs = load() if False else prefs  # UI save already updates global

    if online and now - last_ntp_try >= (NTP_RESYNC_S if clock_synced() else NTP_RETRY_S):
        last_ntp_try = now
        sync_clock()

    # Re-evaluate the schedule ~1 s (DESIGN.md sec. 6); the dimmer only touches
    # the display when the level actually changes. post_prefs applies saves
    # immediately, so the throttle never delays a slider change.
    if now - last_bright >= 1.0:
        last_bright = now
        if dimmer.apply(brightness(prefs)):
            print("brightness", dimmer.level)

    if online and not sleeping(prefs) and now >= poll_backoff_until and now - last_poll > 15:
        last_poll = now
        try:
            last_card = poll_card()
            print(last_card)
        except httpclient.HTTPStatusError as e:
            if e.retry_after:
                poll_backoff_until = now + e.retry_after
            print("poll http", e.status, "retry_after", e.retry_after)
        except Exception as e:
            print("poll", e)  # OSError / RuntimeError / TimeoutError / ValueError: keep last_card

    time.sleep(0.05)

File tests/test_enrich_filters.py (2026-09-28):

"""Host-side checks for lib/enrich.py, lib/filters.py and lib/logos/.

Run: python3 tests/test_enrich_filters.py
Optional: pip install --no-deps adafruit-circuitpython-imageload  (then the
badges are also decoded with the real on-device loader).
"""
import os
import struct
import sys
import tempfile

HERE = os.path.dirname(os.path.abspath(__file__))
ROOT = os.path.join(HERE, "..")
sys.path.insert(0, os.path.join(ROOT, "firmware", "lib"))
sys.path.insert(0, os.path.join(ROOT, "tools"))

import convert_logos  # noqa: E402
import enrich  # noqa: E402
import filters  # noqa: E402
import gen_badges  # noqa: E402
from enrich import AIRLINES, UNKNOWN_KEY, badge_path, lookup, prefix  # noqa: E402
from filters import MIL_RANGES, apply, hidden, is_ga, is_heli, is_mil  # noqa: E402
from hero import candidates  # noqa: E402

LOGOS = os.path.join(ROOT, "firmware", "lib", "logos")
SOURCES = os.path.join(ROOT, "tools", "logo_sources")
ALL_ON = {"hide_heli": True, "hide_mil": True, "hide_ga": True}


def c(hx="a1b2c3", cs="", cat=None):
    return {"hex": hx, "cs": cs, "lat": 0.0, "lon": 0.0, "dist": 1.0,
            "alt": 1000.0, "spd": 100.0, "trk": 0.0, "cat": cat, "age": 0}


def test_prefix_lookup():
    assert prefix("SWA1234 ") == "SWA" and prefix("ual2") == "UAL"
    for bad in (None, "", "N123AB", "N1", "SWA", "CGABC", "XAABC", "12345", "AB1234"):
        assert prefix(bad) is None, bad
    assert lookup("AAL100") == ("American", "aal")
    assert lookup("  fdx3421") == ("FedEx", "fdx")
    assert lookup("ZZZ123") is None and lookup("N123AB") is None and lookup(None) is None
    assert badge_path("swa") == "/lib/logos/swa.bmp"
    assert badge_path(None) == "/lib/logos/_unk.bmp" == badge_path("zzz")


def test_table():
    assert 30 <= len(AIRLINES) <= 60, len(AIRLINES)
    marks = set()
    for icao, row in AIRLINES.items():
        name, mark, bg = row
        assert len(icao) == 3 and icao.isalpha() and icao.isupper(), icao
        assert 0 < len(name) <= 16, name
        assert 2 <= len(mark) <= 3 and all(ch in gen_badges.FONT for ch in mark), mark
        assert 0 <= bg <= 0xFFFFFF, icao
        assert mark not in marks, "duplicate mark " + mark
        marks.add(mark)


def test_heli():
    assert is_heli(c(cat=8))
    for cat in (None, 0, 1, 2, 3, 4, 5, 6, 7, 9, 14):
        assert not is_heli(c(cat=cat)), cat
    assert hidden(c(cat=8), {"hide_heli": True}) == "heli"
    assert hidden(c(cat=8), {"hide_heli": False}) is None


def test_mil():
    for lo, hi in MIL_RANGES:
        assert lo <= hi
        assert is_mil(c(hx="%06x" % lo)) and is_mil(c(hx="%06X" % hi))
    assert is_mil(c(hx="ae1234")) and is_mil(c(hx="adf7c8"))
    assert not is_mil(c(hx="adf7c7"))     # N99999, last US civil address
    assert not is_mil(c(hx="a00001"))     # N1
    assert not is_mil(c(hx="c0cdf8"))     # Canadian civil
    assert is_mil(c(hx="a12345", cs="RCH821"))
    assert not is_mil(c(hx="", cs="")) and not is_mil(c(hx="zzz"))


def test_ga():
    assert is_ga(c(cs="N123AB", cat=2))
    assert is_ga(c(cs="N123AB", cat=0))          # no category: tail-number callsign
    assert is_ga(c(cs="", cat=None))             # no callsign, no category
    assert is_ga(c(cs="ZZZ12", cat=9))           # glider category wins over shape
    assert not is_ga(c(cs="FDX1234", cat=2))     # FedEx Caravan feeder: airline
    assert not is_ga(c(cs="SWA12", cat=None))
    assert not is_ga(c(cs="N123AB", cat=4))      # large aircraft
    assert not is_ga(c(cs="XYZ123", cat=3))      # operator-coded charter/biz jet
    assert not is_ga(c(cs="N911LF", cat=8))      # helicopter -> hide_heli's job
    assert not is_ga(c(hx="ae0001", cs="", cat=0))  # military -> hide_mil's job


def test_apply_with_hero_candidates():
    def row(hx, cs, cat):
        return [hx, cs, "United States", 1000, 1000, -95.75, 30.21, 1000.0, False,
                100.0, 90.0, 0.0, None, 1000.0, "1200", False, 0, cat]
    resp = {"time": 1000, "states": [
        row("a1b2c3", "SWA1234 ", 4),
        row("a2b2c3", "N123AB  ", 2),
        row("a3b2c3", "N911LF  ", 8),
        row("ae0001", "RCH821  ", 6),
    ]}
    cands = candidates(resp, 30.21, -95.75)
    assert [x["cat"] for x in cands] == [4, 2, 8, 6]
    assert apply(cands, {}) is cands
    assert [x["cs"] for x in apply(cands, ALL_ON)] == ["SWA1234"]
    assert [x["cs"] for x in apply(cands, {"hide_heli": True, "hide_mil": True})] \
        == ["SWA1234", "N123AB"]
    assert [x["cs"] for x in apply(cands, {"hide_ga": True})] == ["SWA1234", "N911LF", "RCH821"]


def _parse_bmp(data, expect=None):
    """expect: optional (w, h, used) to assert exactly (letter-mark badges);
    omitted for a real logo, whose size/palette length vary per source."""
    magic, fsize, _r1, _r2, off = struct.unpack_from("<2sIHHI", data, 0)
    hdr, w, h, planes, bpp, comp, isize, _xr, _yr, used, _imp = \
        struct.unpack_from("<IiiHHIIiiII", data, 14)
    assert magic == b"BM" and fsize == len(data) and hdr == 40 and planes == 1
    assert bpp == 4 and comp == 0, (bpp, comp)          # 4-bit indexed, uncompressed
    if expect is not None:
        assert (w, h, used) == expect, (w, h, used)
    row_bytes = ((w * 4 + 31) // 32) * 4
    assert off == 14 + 40 + 4 * used and isize == row_bytes * h == len(data) - off
    pal = [struct.unpack_from("<BBBB", data, 54 + 4 * i) for i in range(used)]
    return w, h, [(r << 16) | (g << 8) | b for b, g, r, _ in pal]
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

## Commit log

2026-09-26 Add TailWatch S3 starter firmware and design doc
    Imports the existing MatrixPortal S3 CircuitPython starter
    (prefs/sun/schedule/bbox helpers, settings UI, code.py stub) and
    the design spec referenced from it.
    Claude-Session: https://claude.ai/code/session_01TnayvoxAYC1K1Yn6hCpV8k
2026-09-26 WIP: blocking-fix workflow progress + nyan cat easter egg scaffold
    In-progress checkpoint from the Opus-designs/Sonnet-Haiku-builds/Fable-checks
    workflow fixing the blocking bugs from the design review (boot.py read-write
    remount, Web Workflow port-80 conflict, form percent-decoding via new
    lib/urldecode.py, prefs handling). More issues are still being worked by the
    background workflow and will land in follow-up commits.
    Also adds lib/nyan.py and lib/buttons.py (HoldButton) for a "hold DOWN for
    5s" easter egg -- not yet wired into code.py's main loop to avoid colliding
    with the workflow's in-flight edits there; wiring lands once it finishes.
    Adds .gitignore for __pycache__/, prefs.json, an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
    [boot.py, code.py]
2026-09-26 nyan: cap animation at 90s, exit early on UP/DOWN press
    play() now accepts should_stop, a zero-arg callable checked continuously
    (not just once per frame) so releasing/pressing a button during playback
    returns to the caller's previous display state immediately rather than
    waiting out the full duration. Default duration_s raised from 8 to 90.
    buttons.HoldButton exposes pressed() (renamed from the private _pressed)
    so callers can also do a plain press check outside the hold-to-trigger flow.
    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
2026-09-26 WIP: sun/timezone workflow progress + nyan sprite recolor
    Blocking-fix workflow progress: lib/sun.py, lib/schedule.py, lib/prefs.py,
    and new lib/tz.py (sun-math fix and timezone offset/DST handling, issues
    #6 and #7). Still in progress for the brightness dimming issue (#8).
    Nyan easter egg: updated frosting/crust/sprinkle/cheek palette colors and
    the shortened leg/foot pixel rows to match a refined reference sprite.
    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
2026-09-26 WIP: brightness dimming fix lands (issue #8) -- blocking group complete
    New lib/dim.py scales rendered colors instead of relying on rgbmatrix's
    on/off display.brightness, per the design review finding that brightness
    wasn't behaving as a real dimmer. code.py updated to use it; DESIGN.md/
    README.md updated accordingly.
    This closes out the last of the 7 blocking issues from the design review.
    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
    [code.py]
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2026-09-26 DESIGN.md: complete the firmware module table
    Fable's independent check of the timezone fix (issue #7) flagged that
    lib/tz.py was missing from the module table (and README's copy-to-device
    list, already fixed by a later commit). Also adds the other modules that
    had landed without a table entry: lib/urldecode.py, lib/buttons.py,
    lib/nyan.py.
    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
2026-09-26 WIP: on-device hero-aircraft selection with hysteresis (issue #9)
    New lib/hero.py implements the on-device hero-selection logic (no cloud
    API, per closed issue #2): tracks the shown aircraft by ICAO hex across
    polls, only switching on a meaningfully-closer challenger (ratio + absolute
    margin + minimum dwell time), a hero leaving the response, or a staleness
    timeout -- fixing the card-flapping issue the design review flagged.
    tests/test_hero.py covers the selection rules with plain python3 (no
    CircuitPython dependencies). DESIGN.md/README.md updated to match.
    Still in progress: issue #10 (enrichment/filters/logo badges), and a
    separate workflow for issues #11 (AP-mode Wi-Fi) and #12 (blocki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
    [test_hero.py]
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2026-09-26 WIP: on-device enrichment, filters, and badge logos (issue #10)
    New lib/enrich.py (callsign-prefix to airline/badge-color lookup, ~50
    carriers), lib/filters.py (helicopter/GA/military detection via OpenSky's
    category field plus verified ICAO military hex-block ranges), and
    lib/logos/ (50 generated 24x24 4bpp letter-mark badges, ~354 bytes each --
    not real airline logos, per DESIGN.md's own non-goal on trademark
    licensing). tools/gen_badges.py regenerates the badge set.
    tests/test_enrich_filters.py covers lookups, filters, and badge decoding
    with plain python3. DESIGN.md/README.md updated; code.py untouched (a
    separate workflow needs it for issues #11/#12).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
    [test_enrich_filters.py]
2026-09-26 DESIGN.md/README.md: finish scrubbing stale cloud-API framing
    Fable's check of issue #9 flagged that section 8 was still headed "Cloud
    API" and described an HTTP endpoint contract, contradicting the on-device
    decision (issue #2). Updates the architecture diagram, security section,
    implementation order, caching section, and README's "Next" list to
    consistently describe the on-device design: no server, no device/cloud
    token, each unit polls OpenSky directly with its own bbox.
    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
2026-09-26 Replace baked-in default coordinates with an obvious placeholder
    lib/prefs.py's DEFAULTS, prefs.example.json, DESIGN.md, and
    tests/test_hero.py's PIN all hardcoded 30.2094/-95.7508, a real-looking
    precise location. Swapped for 30.0000/-95.0000, an unambiguous placeholder.
    Note: this only fixes tracked files going forward -- the original values
    are still present in earlier commits' history. A full-history rewrite
    (git filter-repo --replace-text) to scrub them retroactively was attempted
    and blocked by the auto-mode classifier as a destructive git action across
    already-pushed commits; that needs explicit user sign-off to run.
    Claude-Ses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
    [test_hero.py]
2026-09-26 WIP: AP-mode Wi-Fi provisioning + untrusted-clock gate (issue #11)
    New lib/wifisettings.py (validates and writes CIRCUITPY_WIFI_SSID/PASSWORD
    into settings.toml, TOML-safe escaping, atomic .new/.bak swap) and
    lib/setupscreen.py (panel setup screen showing the AP name/password/URL).
    code.py starts a TailWatch-XXXX setup AP when the configured network is
    empty or unreachable, serves the existing UI plus a Wi-Fi form on it, and
    retries the normal join periodically rather than getting stuck.
    lib/schedule.py gains a clock-validity gate: sleeping()/night() no longer
    blank the panel when NTP hasn't synced and the RTC looks like CircuitPython's
    default epoch, fixing the "stuck dark after a failed N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
    [code.py, test_schedule_clock.py, test_wifisettings.py]
2026-09-26 WIP: Wi-Fi reconnect resilience + HTTP client pattern (issue #12)
    New lib/linkwatch.py: station-mode Wi-Fi watchdog. Notices a dropped link
    within ~2s, retries reconnecting on a backoff schedule (10/20/30/60/60/60s,
    ~4 min total), restarts the local settings HTTP server when the link comes
    back or the IP changes, and hard-resets the board if all reconnects fail
    (landing back in issue #11's setup-AP fallback).
    New lib/httpclient.py: the session-reuse/timeout/close-on-every-path pattern
    poll_card() must use once lib/net.py (the OpenSky client) is built, so it
    never blocks the single-threaded main loop for too long. code.py's poll_card()
    docstring points at it explicitly.
    code.py also gains: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
    [code.py, test_code_linkwatch.py, test_httpclient.py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]
2026-09-26 README: list lib/linkwatch.py and lib/httpclient.py (issue #12)
    These landed in commit b378354 but weren't added to the CIRCUITPY file
    list or bundle-library notes.
    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
2026-09-26 docs: add end-user setup/usage guide
    Non-technical guide for the two device owners: first-time Wi-Fi setup,
    the settings page fields, brightness/night-mode/sleep/filters, what
    NO TRAFFIC/NO LINK mean, moving to a new network, and the Nyan Cat
    easter egg. Corrected one drafting error: the guide referenced an
    http://tailwatch/ mDNS hostname that isn't actually implemented
    (DESIGN.md lists mDNS as an unbuilt stretch goal) -- replaced with
    router-device-list / serial-output instructions.
    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
2026-09-26 lib/prefs.py: validate lat/lon/time-of-day fields (issue #15)
    _clamp() previously left lat/lon and the four HH:MM fields (night/sleep
    start/end) completely unvalidated, and used a bare float() for nm/
    brightness/tz_offset_min that could raise on a malformed stored value.
    Adds _float()/_in_range()/_hhmm() helpers: lat clamped to [-90,90], lon to
    [-180,180], each HH:MM field normalized (e.g. "7:05" -> "07:05") or reset
    to its default with a serial diagnostic on anything unparseable. Also
    covers an OverflowError gap in the existing tz_offset_min guard (round(inf)).
    tests/test_prefs_validation.py covers valid/invalid inputs for every field,
    a malformed-file load/save round-trip, and the apply_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
    [test_prefs_validation.py]
2026-09-26 CSRF guard + write-only API token (issue #14)
    get_prefs/post_prefs returned the full prefs dict including the optional
    OpenSky "token" field in cleartext to any GET on the LAN. There was also
    no CSRF protection on post_prefs/post_wifi -- a Host-only check (considered
    and rejected, see lib/reqguard.py's docstring) doesn't stop it, since a
    CSRF POST from another site still carries the device's own Host header;
    only Origin/Referer actually distinguishes it.
    New lib/reqguard.py: Host must match the device's current address on every
    /api/* route (blocks DNS rebinding); state-changing requests additionally
    require a same-origin Origin (or Referer), rejecting cross-site POSTs with
    403. Wired into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
    [code.py, test_prefs_token.py, test_reqguard.py]
2026-09-26 DESIGN.md sec. 13: accurate, complete acceptance-test coverage (issue #16)
    Section 13 predated most of the actual implementation. Replaces it with
    a table mapping every described behavior to its actual host-side test
    (13.1), a pending list of what's genuinely still untested pending
    lib/net.py and lib/card.py (13.2), and a manual/hardware-only list
    (13.3) -- removing two stale lines ("Two tokens..." from the since-removed
    cloud tier, "Invalid API..." written for the old cloud endpoint).
    Adds tests/test_prefs.py (save/load round trip, .bak fallback, clamps,
    form-vs-JSON merge rules), tests/test_bbox.py (sec. 6 formula + the
    existing cos(lat) floor), tests/test_dim.py (color-scaled dimming, sl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
    [test_bbox.py, test_code_apmode.py, test_code_schedule.py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]
2026-09-26 WIP: 3D-printable enclosure design in progress (OpenSCAD)
    Checkpoint from the in-flight enclosure design agent -- params.scad and
    tailwatch_lib.scad so far. Still writing the per-part files, rendered
    STL/PNG previews, and the README. Not yet a complete, printable design.
    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
    [params.scad, tailwatch_lib.scad]
2026-09-26 WIP: 3D-printable enclosure -- parts, STLs, and preview renders
    Checkpoint: split-frame design (frame_left/frame_right/portal_pod/
    button_rods/bowtie_keys/strap) plus an assembly.scad tying them together,
    each rendered to STL and a preview PNG via OpenSCAD's headless CLI.
    Agent is still iterating on preview camera angles and doing a final
    rebuild pass -- not yet finalized, no README/print-settings doc yet.
    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
    [assembly.scad, bowtie_keys.scad, bowtie_keys.stl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]
2026-09-26 3D-printable enclosure: finalize design against 200x200x250mm bed
    Split-frame enclosure (frame_left/frame_right joined by two bowtie keys,
    straps holding the panel against 45-degree ledges, a board pod for the
    MatrixPortal S3, printed button push-rods for USB-C/DOWN/UP/RESET access
    once wall-mounted, hidden keyhole wall-mount slots). All 6 parts verified
    manifold and within the actual 200x200x250mm print bed (params.scad,
    tools/build.sh, and check_stl.py's default all updated from the initial
    220x220mm target).
    Real dimensions (Adafruit's own Eagle/3D design files, since their Learn
    Guide/product pages were network-blocked): board 63.5x44.45mm, 4x M2.5
    mounting holes at exact coordinates, U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
    [frame_left.stl, frame_right.stl, params.scad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]
2026-09-26 DESIGN.md: document the MatrixPortal S3 screw-terminal power footgun
    Confirmed on real hardware: the board's own 5V/GND screw terminals next
    to the HUB75 connector are output-only, wired straight to USB-C 5V (they
    exist to power a small panel with no external supply). Landing the
    external PSU's barrel-to-terminal adapter on those terminals instead of
    the panel's own power input looks correct but leaves the panel entirely
    dependent on USB -- confirmed by Adafruit's own support guidance for
    this exact symptom (panel goes dark when USB is unplugged despite an
    external supply nominally being connected).
    Claude-Session: https://claude.ai/co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
2026-09-26 WIP: Blender assembly of the enclosure (tailwatch_enclosure.blend)
    blender_import/ holds per-part STLs re-exported from the OpenSCAD source
    with the exact assembly() transform applied (correct position/rotation
    per part, not the print orientation), used to build the Blender scene
    with one object per part and matching materials/colors. Rendered front/
    back/iso previews confirm correct assembly.
    Still in progress on the same agent: a glTF/GLB export of this scene for
    a web-embedded interactive viewer, and a separate CadQuery/STEP rebuild.
    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
    [bowtie_key_1.stl, bowtie_key_1_positioned.scad, bowtie_key_2.stl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]
2026-09-26 enclosure: drop Blender autosave backup, agent's latest preview pass
    tailwatch_enclosure.blend1 is a Blender-generated autosave backup, not
    source -- shouldn't have been committed. Also picks up the agent's
    continued iteration on the assembly previews.
    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
    [tailwatch_enclosure.blend]
2026-09-26 enclosure: add glTF/GLB export for a web-embedded 3D viewer
    web/tailwatch_enclosure.glb (241KB, verified valid glTF 2.0 binary) --
    exported from the same assembled Blender scene as the preview renders,
    for embedding with Google's <model-viewer> web component so visitors
    can rotate/zoom the design in-browser without downloading anything.
    tools/blender_build.py regenerates the .blend, previews, and this
    export in one script.
    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
    [tailwatch_enclosure.blend]
2026-09-26 WIP: enclosure -- Blender rebuild pass + STEP work started
    Blender assembly/GLB updated (looks like a re-export after some upstream
    OpenSCAD tweak); tools/export_blender_stls.sh added for regenerating the
    positioned STLs. STEP/CadQuery work has started: step/tailwatch_params.py
    mirrors params.scad's dimensions as the shared source of truth for the
    parametric rebuild, still in progress.
    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
    [frame_left.stl, frame_right.stl, portal_dummy.stl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]
2026-09-26 enclosure: CadQuery/STEP rebuild of all 6 parts
    step/cadquery_build.py rebuilds all 6 parts as real OpenCascade BREP
    solids (same kernel FreeCAD uses internally) from step/tailwatch_params.py,
    exporting both .step (for FreeCAD/Fusion/etc.) and a cross-check .stl per
    part. All 6 verified manifold and within the 200x200x250mm bed via the
    existing tools/check_stl.py; bounding boxes match the OpenSCAD-exported
    STLs closely.
    Note: portal_pod_cq.stl's volume (38.0 cm3) is notably higher than the
    OpenSCAD version's (14.2 cm3) despite matching bounding boxes -- likely a
    simplification (missing internal cavity/lightening cutouts) in the
    CadQuery rebuild rather than a dimensional error, but not yet c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
    [bowtie_keys.step, bowtie_keys_cq.stl, button_rods.step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]
2026-09-26 enclosure: document the Blender/glTF and STEP deliverables
    README.md updated with sections for the .blend file + web GLB viewer and
    the STEP/CadQuery rebuild, plus a refreshed file listing. All three
    deliverables (Blender, glTF, STEP) are now complete and verified:
    - Blender assembly assembled from positioned STL exports (matching the
    print STLs' facet counts/volumes), 3 rendered preview angles.
    - glTF/GLB (236KB) reimport-verified: 10 objects, correct materials.
    - STEP: CadQuery BREP rebuild of all 6 parts, 5/6 exact bbox match
    against the OpenSCAD STLs (1 off by 0.1mm), all manifold, all
    re-imported and confirmed as valid solids. portal_pod's higher volume
    vs. the OpenSCAD version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
2026-09-26 Rename artifacts/tailwatch-s3/ -> firmware/
    The artifacts/<target>/ nesting was inherited from the original prompt's
    naming convention (anticipating multiple hardware targets). Since this
    repo is single-purpose, flatten to a plain top-level firmware/ directory.
    Updates path references in DESIGN.md, the enclosure README, and
    .gitignore; drops a stale DESIGN.md line about a "Cloud Worker"
    artifacts/tailwatch-api/ directory that no longer applies (cloud tier
    removed, issue #2). All 16 host-side tests and the enclosure STL/STEP
    checks still pass from the new location.
    Claude-Session: https://claude.ai/code/session_01TnayvoxAYC1K1Yn6hCpV8k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
    [assembly.scad, bowtie_key_1.stl, bowtie_key_1_positioned.scad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]
2026-09-26 docs: correct badge budget to 48x48, add CLAUDE.md
    DESIGN.md's card layout hardcoded 24x24 for the badge slot, but the
    actual pixel budget in that layout is up to 48x48 — the current
    tools/gen_badges.py output just happens to be 24x24. Notes issue #18
    (sourcing real carrier logos at the corrected size, keeping the
    generated letter-mark as a fallback) and fixes a stale "shared cloud
    API" line in the Goal section left over from the on-device decision
    (issue #2).
    Also adds CLAUDE.md for future Claude Code sessions in this repo.
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2026-09-26 AP mode: captive-portal DNS hijack + OS probe redirects (issue #21)
    Add lib/captiveportal.py's CaptiveDNS: a non-blocking UDP DNS responder on
    :53 that answers every A/ANY query with the AP's own IP (NOERROR/no-answer
    for anything else), so a joining device's captive-portal detection probes
    resolve to us instead of timing out with no internet in AP mode. code.py
    wires it up in AP mode only, and adds redirect routes for the well-known
    Android/Apple/Windows/Firefox captive-portal probe paths -- redirecting is
    what makes the OS conclude there's a portal and auto-launch its sign-in
    browser, rather than trying to mimic each OS's exact expected success body.
    Fixes the test_code_linkwatch.py fake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
    [code.py, test_captiveportal.py, test_code_apmode.py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]
2026-09-26 badges: source real airline logos for 15/44 carriers (issue #18)
    The project owner has explicitly overridden DESIGN.md sec. 2's original "no
    airline trademark artwork" non-goal for this personal, non-commercial build,
    and wants real carrier logos used where they can be sourced, at the
    corrected 48x48 badge budget (sec. 9). tools/gen_badges.py's generated
    letter-mark badges remain the fallback for every airline without one -- nothing
    about that generator's own output changes.
    - tools/logo_sources/: 15 real logo SVGs (American, Delta, United, Southwest,
    JetBlue, FedEx, UPS, Air Canada, British Airways, Lufthansa, KLM, Air
    France, Emirates, Qatar Airways, Turkish), sourced from the CC0-lic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
    [test_enrich_filters.py]
2026-09-26 badges: source real airline logos for remaining 34 carriers (issue #18)
    All 49 AIRLINES entries now have a real logo; the letter-mark generator
    is left as the fallback only for the generic _unk badge (or any airline
    added later before a logo is sourced for it).
    Sources that worked: img.logo.dev/<domain>?format=png (a per-carrier
    domain lookup, using logo.dev's own published demo token -- no account
    of ours) for all 34. These are raster, multi-color marks, so they go
    through convert_logos.py's until-now-unexercised "photo" mode, which
    keeps the source's own brand colors instead of tinting to the AIRLINES
    accent -- test_enrich_filters.py's real-logo checks assumed every real
    logo was silhouet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
    [test_enrich_filters.py]
2026-09-26 badges: fix wrong/illegible logos in first Simple Icons pass (issue #18)
    User review flagged two problems in the original 15 Simple Icons
    silhouettes, both fixed by swapping to a logo.dev/photo-mode source
    (same pipeline as the 34-carrier batch):
    - afr: the current SVG was just a plain blue diagonal slash, no
    wordmark or Air France red -- didn't read as Air France's mark at
    all. Replaced with airfrance.com's logo.dev fetch (slash + AIRFRANCE
    wordmark, correct brand red); the wordmark itself washes out at 48px
    (photo mode's known small-text limitation) but the slash alone is a
    clear improvement over the old shape/color.
    - dal: the current SVG is Delta's full "DELTA" wordmark + wid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
2026-09-26 Move host-only docs/tools/tests to repo root; firmware/ holds only on-device payload
    Only what actually gets copied to the CIRCUITPY drive should live under
    firmware/. Moves DESIGN.md, README.md, docs/, enclosure/, tools/, and
    tests/ to the repo root (git mv, history preserved) alongside CLAUDE.md,
    leaving firmware/ with just boot.py, code.py, prefs.example.json,
    settings.toml.example, lib/, and www/.
    Fixes path constants in the moved host-side Python that reach into
    firmware/lib/ (tools/gen_badges.py, tools/convert_logos.py, and the
    sys.path.insert/CODE constants across tests/*.py), updates DESIGN.md and
    README.md's bare lib/code.py/boot.py/www/ path references to carry the
    firmware/ prefi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
    [assembly.scad, bowtie_key_1.stl, bowtie_key_1_positioned.scad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]
2026-09-28 badges: real Southwest (swa) heart logo from Wikimedia Commons
    logo.dev's fetch for southwest.com was bad/near-blank during the earlier
    accuracy review, so swa was left on its Simple Icons silhouette (a
    monochrome heart tinted to the AIRLINES accent). Wikimedia Commons -- a
    dead end during the original 34-carrier sourcing push -- is reachable
    again and has Southwest's real 2014 logo SVG, with the tri-color heart
    as separate <path> elements from the wordmark text. Cropped to just the
    heart paths for a correctly-colored icon-only source.
    Needed two things convert_logos.py didn't have: forcing "photo" mode on
    an .svg source (detect_mode() assumes .svg means a single-color
    silhouette, wrong her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
    [test_enrich_filters.py]
2026-09-28 Build lib/net.py: the real OpenSky HTTPS client (issue #26)
    lib/net.py hits OpenSky's /states/all directly with the device's own
    bbox and extended=1, going through lib/httpclient.py's shared
    Session/timeout/budget contract, with an optional Bearer token
    (prefs.token) to raise the anonymous rate limit. Raises rather than
    swallowing a failure -- that policy belongs to the caller.
    code.py:poll_card() is wired to it for real: net.py -> filters.apply()
    -> Hero.select() -> enrich.lookup(), replacing the placeholder card.
    route/type/city/phase stay "" since nothing on-device supplies that
    data yet (raw ADS-B has no route/airport info). The main loop now
    backs off past a 429's Retry-After instead o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
    [code.py, test_code_linkwatch.py, test_code_poll.py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]
2026-10-03 Build lib/card.py: the real 128x64 display renderer (issue #27)
    Replaces code.py's placeholder bars with a real Card: badge (up to
    48x48, real logo or letter-mark) plus airline/flight+route/type text
    beside it, city+phase and alt/spd/trk below, in fixed slots per
    DESIGN.md sec. 9's layout. An empty route/type/city/phase (issue #26:
    no on-device data source for them yet) leaves its slot blank rather
    than drawing placeholder text, so the layout already looks right the
    day those fields start getting populated.
    Badge palette handling needed a real fix, not just a note: adafruit_
    imageload.load() returns a brand new Palette object every hero swap,
    and Dimmer.add_palette() only ever appends, so s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
    [code.py, test_code_linkwatch.py, test_code_poll.py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]
